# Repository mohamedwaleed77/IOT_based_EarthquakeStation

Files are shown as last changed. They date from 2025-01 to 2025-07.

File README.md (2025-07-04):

# 🌍 IoT-Based Earthquake Detection Station

An intelligent real-time seismic monitoring system designed to detect and classify earthquake activity. The project is composed of two main components:

- 📡 **Station Side** – Collects seismic acceleration data and sends it wirelessly via UDP.
- 🖥️ **Server Side** – Receives, processes, and classifies data using machine learning, and visualizes the results via a web dashboard.

---

## 🧱 System Architecture

A high-level overview of how data flows between the station and the server.

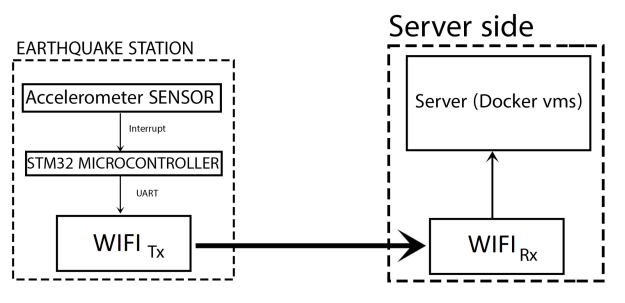
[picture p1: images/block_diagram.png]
System Block Diagram


---

## 🖥️ Server Side Overview

The server processes incoming seismic data and makes real-time predictions using a trained Random Forest model. It then updates a live web dashboard to notify users of potential earthquake activity.

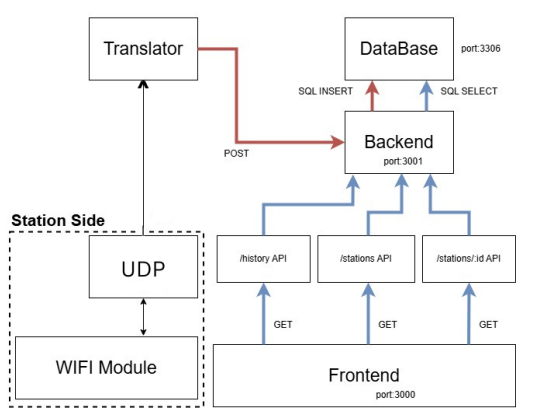
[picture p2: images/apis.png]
API Flow Diagram


---

## 🔩 3D-Printed Enclosure Design

The station hardware is housed in a custom-designed 3D-printed case to protect and organize components.

| Design Phase | Images |
|---|---|
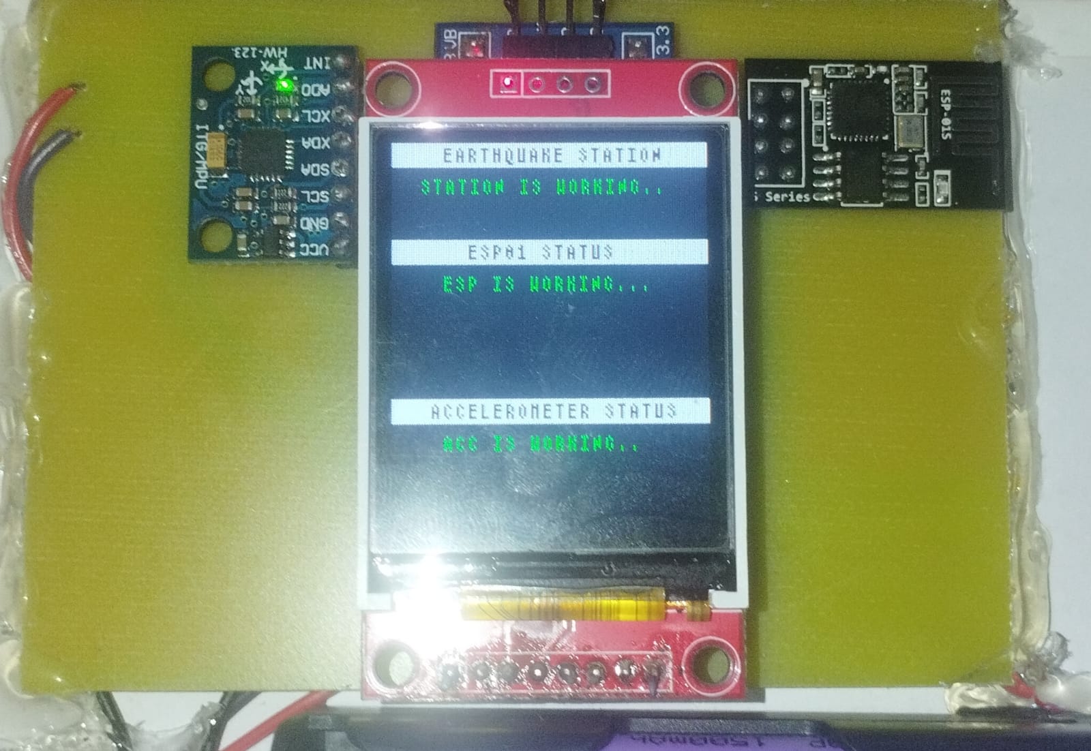
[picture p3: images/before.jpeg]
Before Assembly
| 📦 Before Assembly |  |
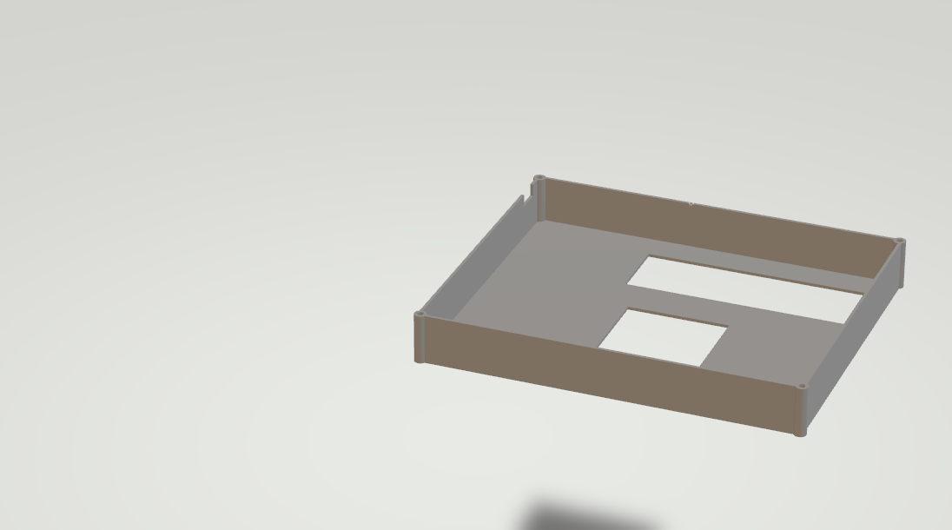
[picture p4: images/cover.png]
Cover
| 🧱 Case Cover |  |
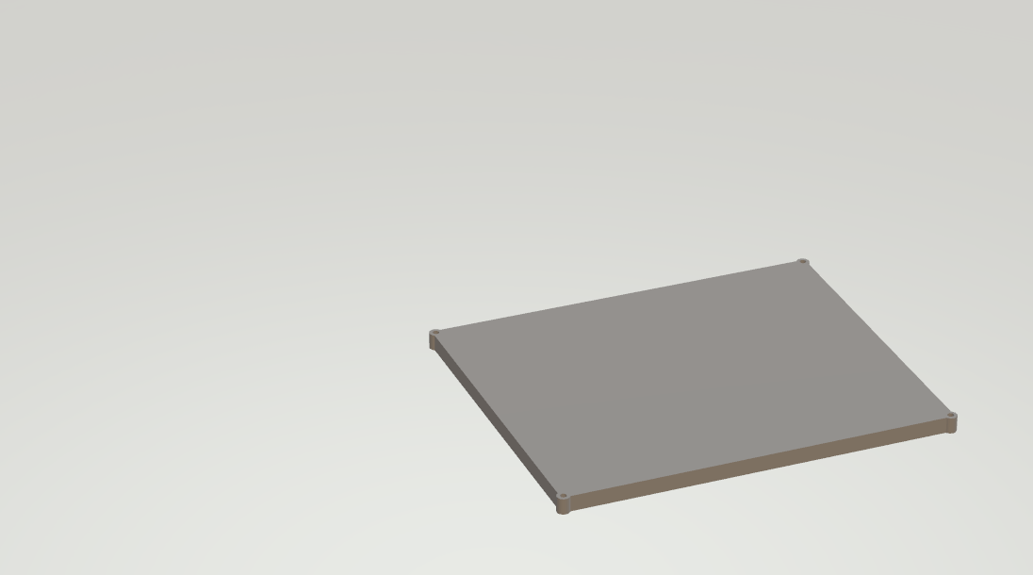
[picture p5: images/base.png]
Base
| ⚙️ Case Base |  |
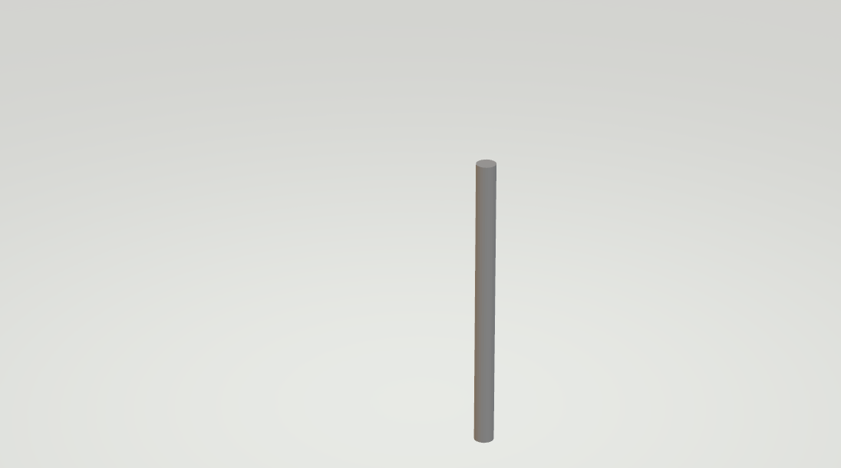
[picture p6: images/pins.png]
Pins
| 🔌 Pin Alignment |  |
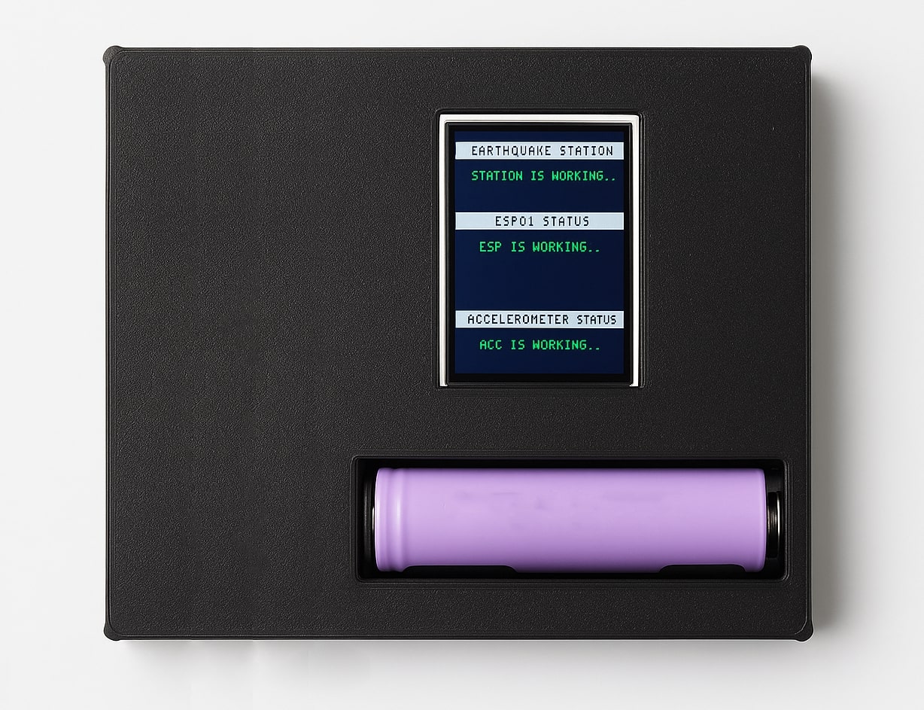
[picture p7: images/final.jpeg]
Final Assembly
| ✅ Final Assembly |  |
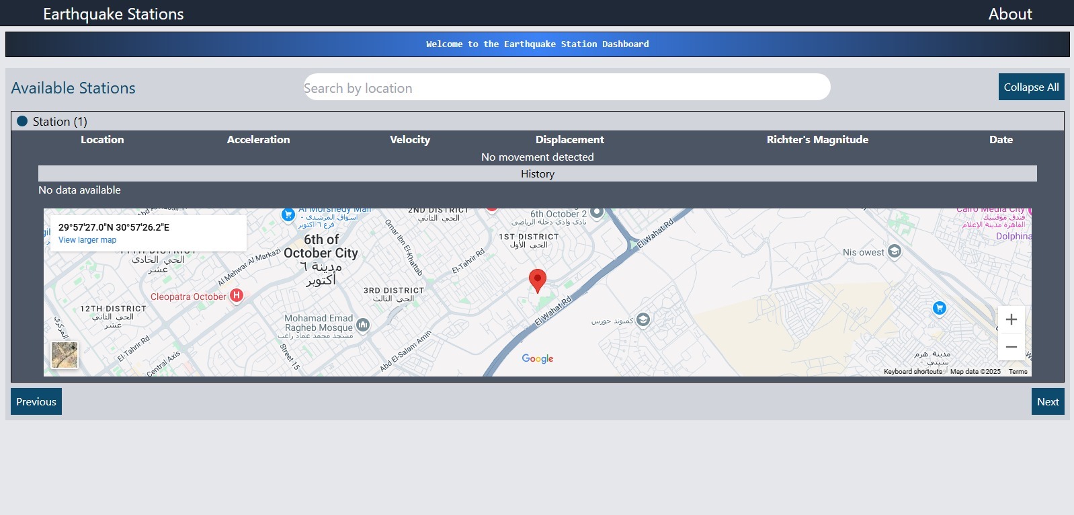
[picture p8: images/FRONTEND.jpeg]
Website
| 🌍 Website |  |

---

## 🛠️ PCB and Wiring Design

PCB and wiring layout for connecting the STM32 microcontroller to the accelerometer and Wi-Fi module.

| Design Phase | Images |
|---|---|
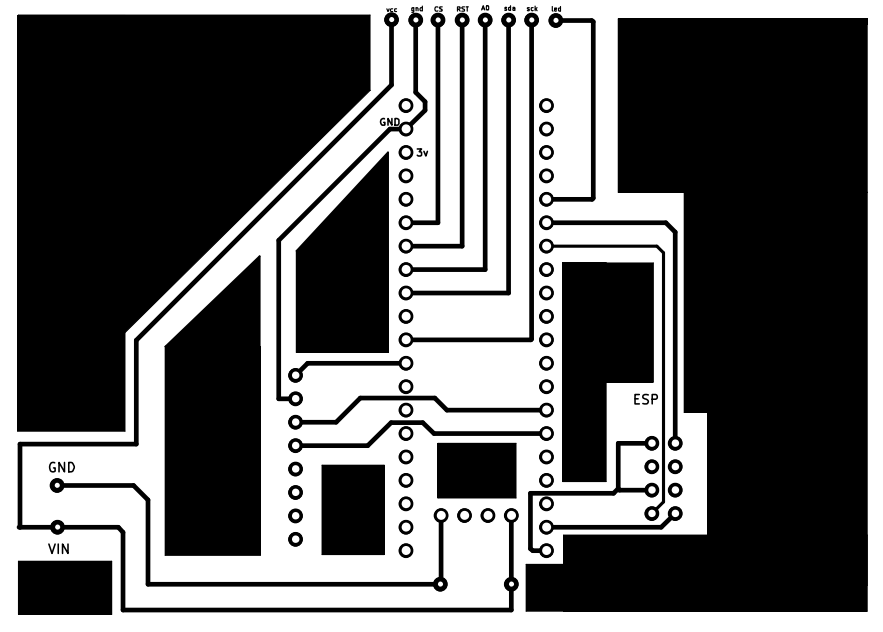
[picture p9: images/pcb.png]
PCB Design
| 🖨️ PCB Design |  |
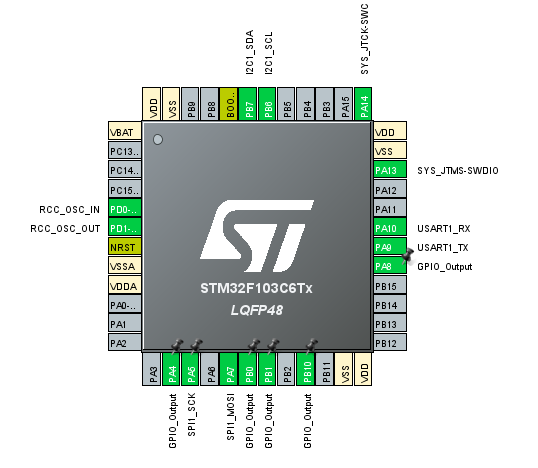
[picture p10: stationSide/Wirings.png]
Wirings
| 🔌 Wiring Diagram |  |

---

## 🚀 Key Features

- **Real-Time Seismic Detection** – Uses a calibrated accelerometer to monitor ground motion.
- **False Alarm Filtering with AI** – A Random Forest model classifies real earthquakes from non-seismic events.
- **Live Web Dashboard** – Displays live events and predictions.
- **Energy-Efficient Design** – Activates only during vibration for optimal power usage.
- **Modular and Scalable** – Easily deploy multiple stations for broader coverage.

---

## 🧠 How It Works

- The station samples acceleration data using an MPU-6050 sensor.
- If shaking is detected, the system transmits the first 200 acceleration readings via UDP.
- The server receives this data and classifies it using a pre-trained Random Forest model.
- If it’s an earthquake, the event is logged and displayed on a web interface.
- If its not an earthquake, the server chooses to ignore the data.

---

## 📁 Project Structure

```
.
├── Design Autocad/             # 3D-printed enclosure and mechanical design files
├── Machine learning Tests/     # Model evaluation, training notebooks, and experiments
├── backend/                    # Flask API for data ingestion and prediction
├── database_init/              # SQL database schema and initialization scripts
├── frontend/                   # Web dashboard for visualizing seismic events
├── images/                     # System diagrams, 3D prints, and screenshots
├── stationSide/                # STM32 code, sensor logic, and UDP transmission
├── Grad_Thesis_Book_Latex.pdf  # The graduation book 
└── README.md                   # Project overview
```

---

## 💡 Authors

- Abdulrahman Sallam  
- Mohamed Abdelfattah

---

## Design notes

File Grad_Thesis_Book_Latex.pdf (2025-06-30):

October University for Modern Science & Arts Faculty of Engineering

Department of Computer Systems Engineering

### IoT Wireless Earthquake Station

### A Graduation Project Submitted in Partial Fulfillment of the Requirements of

### B.Sc. Degree in Computer Systems Engineering

### Part II

### Prepared By Abdulrahman Alsayed Sallam 212421 Mohamed Waleed Abdelfattah 203659

### Supervised By Dr. Ehab Salaheldin Awad

2024/2025

Abstract

This project presents a cost-effective IoT-based Earthquake Station designed to detect seismic activity using an accelerometer and Wi-Fi for real-time data transmission. The system measures ground motion and operates only during seismic events, ensuring optimal energy efficiency, an essential feature for remote or off-grid locations. The system is only activated when needed. The project emphasizes reliable earthquake detection, efficient communication, and energy-saving techniques, adhering to a streamlined design approach. To address potential challenges, the agile development methodology is adopted, enabling flexibility and continuous refinement throughout the project lifecycle.

ii

Acknowledgement

We sincerely thank Dr. Prof. Ehab Salaheldin Awad for his great guidance and support in this project and for his supervision of our project. We are also grateful to Dr. Prof. Ahmed Ayoub and Dr. Prof. Ahmed Alenany for their invaluable advice and help.

iii

# Contents

1 Introduction | 1
2 Literature Review | 9
2.2.5 | Earthquake Detection Using Supervised Machine Learning and
3 Project Background | 29

iv

4 Proposed System Design | 53

v

4.4 Case Design | 67
4.5 Summary | 67
5 Implementation | 69
5.1 Hardware Implementation | 69
5.1.1 | Sensor Module (Seismic Data Acquisition) | 69
5.1.2 | Processing and Communication Unit | 70
5.1.3 | Power Management System | 71
5.2 Software Implementation | 71
5.2.1 | Firmware Development (STM32 - C Programming) | 71
5.2.2 | Server-Side Processing (Python) | 72
5.2.3 | User Interface | 73
5.3 System Integration | 73
5.3.1 | Sensor Layer | 74
5.3.2 | Communication Layer | 74
5.3.3 | Processing and Visualization Layer | 74
5.4 Summary | 75
6 Testing | 77
6.1 Testing Setup | 77
6.2 Testing Separate H/W or S/W Components and Units | 77
6.2.1 | Unit Testing | 77
6.2.2 | Integration Testing | 78
6.2.3 | System Testing | 78
6.2.4 | Testing Integrated System | 80
6.2.5 | A/B Testing | 80
6.2.6 | Test Cases | 81
6.3 Problems Encountered | 94
6.4 Results and Discussions | 95
6.5 Summary | 96
7 Cost Analysis | 97
7.1 One-Time Costs | 97
7.2 Recurring Cost | 98
7.3 Summary | 98
8 Time Plan | 99
9 Conclusions and Future Work | 101
9.1 Conclusions | 101
9.2 Future Work | 102

vi

References | 108

A System code
0.1 translator.py |
0.2 READINGS_ONLY.py |
0.3 docker-compose.yml |
0.4 Station Side Code |
0.4.1 | ESP01.h |
0.4.2 | ESP_01_SECRET_KEYS.h |
0.4.3 | MPU6050.h |
0.4.4 | fonts.h |
0.4.5 | main.h |
0.4.6 | st7735.h |
0.4.7 | ESP01.c |
0.4.8 | MPU6050.c |
0.4.9 | fonts.c |
0.4.10 main.c |
0.4.11 st7735.c |
0.5 Database Code |
0.5.1 | station.sql |
0.5.2 | database.js |
0.6 Frontend |
0.6.1 | index.html |
0.6.2 | index.css |
0.6.3 | index.js |
0.6.4 | App.test.js |
0.6.5 | reportWebVitals.js |
0.6.6 | setupTests.js |
0.6.7 | Introduction.js |
0.6.8 | about.js |
0.6.9 | history.js |
0.6.10 home.js |
0.6.11 navbar.js |
0.6.12 station_info.js |
0.7 Backend Code |
0.7.1 | checkStationExists.js |
0.7.2 | controller.js |
0.7.3 | routes.js |
0.7.4 | Dockerfile |
0.7.5 | index.js |
| vii

0.8 Machine Learning Models |

viii

List of Abbreviations

ANN | Aritificial Neural Network
API | Application Programming Interface
AUC | Area Under Curve
AWS | Amazon Web Services
BMKG | Meteorology, Climatology, and Geophysical Agency
CRNN | Convolutional-Recurrent Neural Network
EEW | Earthquake Early Warning
ER | Entity Relationship
FFT | Fast Fourier Transform
GSM | Global System for Mobile communication
HTTP | Hypertext Transfer Protocol
IDE | Integrated Development Environment
IMU | Inertial Measurement Unit
InSAR | Interferometric Synthetic Aperture Radar
IoT | Internet of Things
Kbps | Kilo bits per second
LTA | Long-Term Average
Mbps | Mega bits per second
MEMS | Micro-Electro-Mechanical Systems
MPU | Motion Processing Unit
MTBF | Mean Time Between Failures
ROC | Receiver Operating Characteristic
STA | Short-Term Average
STM | Synchronous Transport Module
SVD | Singular Value Decomposition
TP-link Twisted Pair link
UART | Universal Asynchronous Receiver-Transmitter
UDP | User Datagram Protocol
UI | User Interface
WEA | Wireless Emergency Alert

ix

x

# List of Figures

1.1 Block Diagram for Japan’s EEW [9] | | 3
2.1 Model for 19th Century Seismographs [3] | | 9
2.2 MEMS Accelerometer Model Diagram [19] | 10
2.3 Mugla Journal IoT-Based Earthquake Warning System General Design
[10] | 12
2.4 Lovely Professional University Earthquake System Block Diagram [11] . 14 2.5 Perwej, Dr. Yusuf & Jitendra Earthquake System Block Diagram [12] . . 16
2.6 ANN Model of Khan et al. System [16] | 18
2.7 Khan et al. Earthquake Alert Final Device [16] | 19
2.8 Direction Display to Evacuation Site Using Google Maps [15] | 21
2.9 Direction Display to Evacuation Site Using Google Maps [15] | 21
2.10 Notification Showing Earthquake Warning [15] | 22
2.11 UI of their Mobile Application [15] | 23
2.12 Mobile-Based Earthquake Early Warning System Architecture [15] . . . 23
2.13 Bassetti et al. using ESP8266 for the webserver | 26
3.1 Graph Between ∆ km and A0 | 35
3.2 Kobe Earthquake Acceleration Graph | 38
3.3 Kobe Earthquake Frequency Graph (After Fourier Transform) | 39
3.4 Cloud Server Architecture | 41
3.5 ROC Curve of Gradient Boosting Model | 43
3.6 ROC Curve of Gradient Boosting Model | 45
3.7 ROC Curve of LightGBM Model | 47
3.8 ROC Curve of Random Forest Model | 49
4.1 General Block Diagram of our System | 59
4.2 More Detailed Block Diagram for Server Side | 59
4.3 Block Diagram of How our API Works | 60
4.4 Use Case Diagram of our System | 61
4.5 Sequence Diagram of our System | 62
4.6 Activity Diagram of our System | 63

xi

4.7 Entity Relationship Diagram of our System | 64
4.8 High-Fidelity Wireframe of our System | 65
4.9 Circuit Diagram of our System | 66
4.10 PCB Design Diagram of our Station | 66
4.11 Case Design for the Station | 67
6.1 Earthquake Simulator Circuit Design with Bass Shaker | 79
6.2 Vibration Switch and Transistor Power Saving Solution | 94

xii

# List of Tables

2.1 Earthquake Detection ANN Models Results | 18
2.2 Comparison of Earthquake Detection Projects | 27
3.1 Comparison of Physical and Cloud Servers | 41
3.2 Naive Bayes Model Results for False Alarm Detection | 42
3.3 Gradient Boosting Model Results for False Alarm Detection | 44
3.4 LightGBM Model Results for False Alarm Detection | 47
3.5 Random Forest Model Results for False Alarm Detection | 48
6.1 Test case for seismic event detection | 81
6.2 Test case for power efficiency | 82
6.3 Test case for real-time web interface updates | 83
6.4 Test case for false alarm detection with frequency threshold | 84
6.5 Test case for Richter magnitude calculation | 85
6.6 Test case for sensor to STM32 communication | 86
6.7 Test case for STM32 to ESP-01 communication | 87
6.8 Test case for multiple station synchronization | 88
6.9 Test case for AI model integration for false alarm filtering | 89
6.10 Test case for full path data flow from accelerometer to web interface. . . 90
6.11 Test case for bass shaker-based earthquake simulation | 91
6.12 Test case for real-world earthquake detection | 92
6.13 Test case for cross-platform system compatibility using Docker | 93

8.1 Gantt chart illustrating the main project milestones, duration, and task
holder | 99

xiii

## Chapter 1

# Introduction

### 1.1 How Earthquakes Work

Earthquakes occur due to the sudden release of energy along faults in the Earth’s crust, typically caused by tectonic plate movements [1]. This release generates seismic waves that travel through the Earth, carrying vital information about the earthquake’s origin, magnitude, and intensity. Seismic waves are classified into three main types [2]:

- P-waves: The fastest seismic waves that travel through both solid and liquid layers of the Earth. They cause minimal damage but serve as the first indicators of an earthquake.
- S-waves: Slower than P-waves and capable of moving only through solid materials. These waves cause significant ground shaking and structural damage.
- Surface Waves: The slowest yet most destructive waves, responsible for the majority of structural damage during an earthquake.

### 1.2 Methods of Earthquake Detection

Traditional earthquake detection relied on seismographs, stationary instruments that record ground motion. Developed in the 19th century [3], these instruments provided the first quantitative measurements of earthquake intensity and location. However, they required centralized processing and lacked real-time capabilities, limiting their effectiveness for early warning applications.
With advancements in digital technology, earthquake monitoring has evolved significantly. Modern detection systems utilize accelerometers, which measure ground acceleration and detect sudden seismic events in real time. Micro-Electro-Mechanical Systems (MEMS) accelerometers have made earthquake detection more compact, cost-effective, and easily deployable in diverse environments [4].
One of the most critical aspects of modern earthquake detection is P-wave early warning systems. P-waves, which travel faster than S-waves and surface waves, can be detected before the more destructive shaking begins. By analyzing P-wave characteristics, it is possible to estimate the earthquake’s magnitude and provide early warnings seconds to minutes before the main shaking occurs [2].

### 1.2.1 Project Relevance and Contributions

Building upon these principles, our project aims to develop a cost-effective, energy-efficient, and scalable IoT-based earthquake detection system. By leveraging real-time P-wave analysis, signal processing techniques (such as Fast Fourier Transform), and efficient data transmission, our system enhances early warning capabilities. Unlike traditional seismic networks that rely on centralized data processing, our system is designed for distributed deployment, enabling faster and more localized detection.
By integrating modern accelerometer technology, real-time data transmission, and advanced signal processing, this project contributes to the ongoing efforts in earthquake early warning systems, offering a reliable and practical solution for seismic monitoring.

### 1.3 Problem Definition

Earthquakes are among the most powerful and unpredictable natural disasters, with an average of 20,000 occurring globally each year [5]. Most of these are minor and barely noticeable, but around 15 major earthquakes annually are capable of causing widespread destruction in mere seconds [6]. A tragic example is the 2011 Tohoku earthquake in Japan, which triggered a massive tsunami, resulting in nearly 20,000 fatalities and billions of dollars in damage [7]. Earthquakes strike without warning, collapsing buildings, disrupting infrastructure, and leaving communities in chaos. With such immense risks to human life and economic stability, it is critical to develop systems that can mitigate their impact through early detection and warning mechanisms. Although earthquakes cannot be predicted with certainty, early warning systems have been implemented in high-risk regions. Japan’s Earthquake Early Warning (EEW) system [8], shown in Figure 1.1, detects initial seismic waves (P-waves) and provides warnings seconds to minutes before the arrival of more destructive S-waves [2]. These systems enable automated responses such as halting trains, stopping surgeries, and issuing evacuation alerts, significantly reducing injury and damage.
However, while these centralized EEW systems are highly effective, they rely on large-scale sensor networks and extensive computational infrastructure, making them costly and inaccessible for low-income or remote areas. Additionally, continuous data transmission and centralized processing introduce latency and power consumption issues, limiting their feasibility for battery-powered or IoT-based deployments.

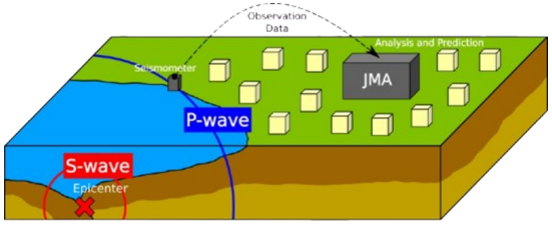
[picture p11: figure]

Figure 1.1: Block Diagram for Japan’s EEW [9]

Research Gap & Project Motivation: To address these challenges, this project proposes a cost-effective, energy-efficient, and scalable IoT-based earthquake detection system. By leveraging real-time P-wave analysis, optimized data transmission, and advanced signal processing techniques (such as Fast Fourier Transform), this system aims to improve early warning capabilities while minimizing power consumption and infrastructure requirements. Unlike traditional EEW systems, the proposed solution focuses on local detection and decentralized processing, allowing for rapid response even in resource-constrained environments.

### 1.4 State of the Art

1. IoT-Based Earthquake Detection Systems: Many modern earthquake detection systems, including our project, Mugla Journal IoT-based earthquake warning system[10], Lovely Professional University earthquake alert system [11], and Perwej et al.’s IoT-based seismic monitoring system [12], they all leverage IoT technologies to monitor seismic activity in real time. These systems utilize networks of accelerometers and other sensors to detect ground motion and transmit data for analysis. IoT-based earthquake detection systems offer several key advantages:
- Scalability: IoT networks enable the deployment of large-scale sensor arrays across various geographical regions, improving earthquake detection coverage.
- Cloud Integration: Many systems integrate with cloud computing for centralized data processing, storage, and real-time accessibility.
- Versatile Applications: These systems are used for various purposes, including early warning alerts, scientific research, and structural health monitoring.

2. Mobile-Based Earthquake Alert Systems: Systems such as ShakeAlert® in the United States [13], Ben et al.’s earthquake detection using GSM [14] and early warning system in mobile-based impacted areas [15] utilize smartphone networks and a combination of ground-based seismometers and mobile sensors to provide real-time earthquake warnings. These systems have proven to be highly effective but require significant infrastructure and government support for large-scale deployment. Key advantages of mobile-based alert systems include:
- Direct User Notifications: Alerts are delivered instantaneously to users via mobile applications, ensuring rapid dissemination of warnings.
- Leveraging Existing Infrastructure: These systems make use of cellular networks, making them highly scalable and cost-effective.
- Optimized for Urban Areas: Mobile-based alerts work best in densely populated regions with robust communication infrastructure, where quick warnings can help mitigate casualties.
3. Artificial Intelligence-Based Earthquake Detection Systems: Recent advancements in earthquake detection have incorporated Artificial Intelligence (AI) and Machine Learning (ML) techniques to enhance accuracy and reduce false alarms. Systems such as Khan et al.’s earthquake detection using supervised machine learning and novel feature extraction [16] utilize Artificial Neural Networks (ANNs) to classify seismic events based on extracted features from accelerometer data. These systems analyze time-series seismic data using feature extraction methods to differentiate between real earthquakes and background noise.

Key Advantages of AI-Based Systems:

- Improved Classification Accuracy: AI models can learn from vast amounts of seismic data, improving their ability to distinguish between actual earthquakes and false alarms.
- Adaptive Learning: Machine learning models can be retrained with new data, making them adaptable to different seismic conditions and regions.
- Feature Engineering for Enhanced Detection: The integration of advanced feature extraction techniques (e.g., FFT, SVD, MAX_ZC, and MIN_ZC) enhances the model’s ability to capture key earthquake characteristics.
- Reduced False Positives: Unlike threshold-based detection methods, AI systems can incorporate multiple features to refine decision-making, reducing false alarms caused by environmental vibrations.

Limitations of AI-Based Systems:

- Computational Cost: Training and deploying AI models require higher processing power, which may not be feasible for low-power embedded systems.
- Need for Large Datasets: ML models require extensive labeled seismic datasets for training, which may not always be readily available.
- Potential Overfitting: If not properly trained, AI models may overfit to specific types of seismic activity, reducing generalization to new events.
- No Current Reliable AI Based Warning: Currently due to how unpredictable earthquakes are, there’s no high accuracy AI’s that have been designed to create early warnings before the p-waves, however as AI continues to evolve in the future it can be used to predict earthquakes before they occur but to today standards unfortunately they can’t be used reliably, for example the best AI results for earthquake prediction before the P-wave was done by researchers at the university of Texas, where they were able to predict up to 70% of earthquakes before they happen in China, however their AI would only work in a specific area in china, they said "We’re not yet close to making predictions for anywhere in the world, but what we achieved tells us that what we thought was an impossible problem is solvable in principle" [17].

### 1.5 Aim and Objectives

We aim to To develop a cost-effective, energy-efficient, IoT-based earthquake detection system that leverages P-wave data to predict the final earthquake magnitude (Richter scale) in real time providing early warning before the more destructive S-waves arrive. We would achieve our aim by following these objectives:-

- Implement Real-Time Signal Processing: Design and apply filtering, Fast Fourier Transform (FFT), and Short-Term Average over Long-Term Average (STA/LTA) algorithms to extract relevant seismic features from acceleration data in real time.
- Develop Magnitude Estimation Algorithm: Implement a method for computing Richter magnitude using P-wave and S-wave arrival times and peak ground acceleration from sensor input.
- Integrate Hardware and Software: Program the STM32 microcontroller in C to manage sensor input, process data locally, and transmit relevant seismic data through a Wi-Fi-enabled IoT framework.
- Implement Event-Driven Activation Logic: Design a vibration-triggered mechanism that activates the system only upon detection of potential seismic motion, reducing unnecessary processing cycles.

- Support Multi-Station Operation: Architect the system to allow deployment of multiple independent detection nodes, with coordinated data aggregation for broader seismic coverage.
- Develop a Real-Time Monitoring Interface: Build a responsive web-based interface to visualize live seismic data, including detected events, sensor status, and historical trends.
- Evaluate System Accuracy and Reliability: Compare the system’s seismic event detection and magnitude estimation results with validated datasets, and iteratively adjust filtering thresholds and model parameters for improved performance.

### 1.6 Contributions and Uniqueness

- Cost-Effective Sensor Design: The system utilizes only an accelerometer rather than combining it with a gyroscope, reducing hardware costs while maintaining adequate accuracy through advanced signal processing techniques.
- Energy-Efficient Operation: A vibration-triggered mechanism ensures that the system activates only when seismic activity is detected. This targeted power usage conserves energy, making it ideal for deployment in remote or off-grid locations.
- Real-Time P-Wave Analysis for Early Warning: By processing P-wave data in real time, the system can predict the final earthquake magnitude before the arrival of the more destructive S-waves, thus providing crucial extra seconds for early warning.
- Robust IoT Integration: The system is built on an STM32 microcontroller, which offers low-level control and energy efficiency, coupled with Wi-Fi connectivity for real-time data transmission. This design supports centralized monitoring and scalable deployment across distributed sensor networks.
- Advanced Feature Extraction: Beyond standard metrics such as RMS acceleration, the system extracts detailed P-wave features including peak acceleration, duration, energy content, and frequency metrics (both peak and dominant frequencies) to enhance the accuracy of magnitude prediction.
- Adaptability and Scalability: The modular design allows for the easy integration of additional sensors or advanced algorithms (e.g., machine learning) in future iterations. This ensures that the system can be scaled and adapted to a variety of environmental conditions and evolving requirements.

### 1.7 Thesis Structure

This thesis is structured as follows:

- Chapter 1 - Introduction: Provides an overview of the project, including its objectives, significance, and a comparison with existing earthquake detection systems.
- Chapter 2 - Literature Review: Examines the principles of earthquake detection, signal processing techniques, and the evolution of seismic monitoring technologies.
- Chapter 3 - Project Background: Establishes the context and motivation behind the development of the earthquake detection system, highlighting real-world challenges, limitations of existing approaches, and the unique advantages offered by the proposed solution.
- Chapter 4 - System Design: Defines the system architecture, hardware components, software framework, and design specifications of the proposed earthquake detection system.
- Chapter 5 - System Implementation: Describes the hardware and software implementation, including microcontroller firmware development and the web-based monitoring platform.
- Chapter 6 - Testing and Evaluation: Discusses the testing methodologies, test cases, and evaluation results to validate the accuracy, reliability, and efficiency of the system.
- Chapter 7 - Cost Analysis: Provides a financial assessment of the system, covering hardware costs, operational expenses, and scalability considerations.
- Chapter 8- Time Plan: Showcases the main goal points of the project and how long the task will take with the usage of gantt chart.
- Chapter 9 - Conclusions and Future Work: Summarizes the findings, evaluates the project’s impact, and outlines potential future improvements to enhance system performance.

## Chapter 2

# Literature Review

### 2.1 History

The field of earthquake detection has undergone a remarkable evolution over the past two centuries. In its earliest days, detection relied on traditional seismographs—stationary instruments designed to record ground motion during seismic events. Developed in the 19th century, these early seismographs revolutionized our understanding of earthquake dynamics by providing the first quantitative measurements of seismic intensity and location. However, these instruments were limited by their immobility and reliance on centralized systems, which significantly hampered real-time detection and timely warning dissemination [18].

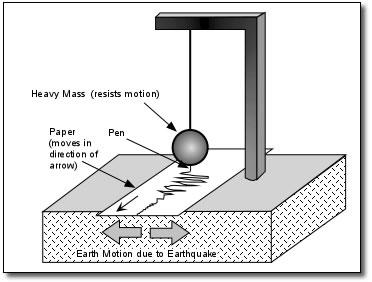
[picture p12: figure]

Figure 2.1: Model for 19th Century Seismographs [3]

The advent of digital technology in the late 20th century marked a major turning point. Computerized monitoring systems emerged, enabling faster and more accurate data processing. This digital revolution in seismology paved the way for the development of advanced methods capable of near real-time analysis of seismic events. Among the most significant breakthroughs was the invention of Micro-Electro-Mechanical Systems (MEMS) accelerometers. These sensors, with their compact size, low cost, and high sensitivity, have enabled the creation of scalable, IoT-based earthquake detection systems that are not only cost-effective but also capable of providing rapid alerts [4].

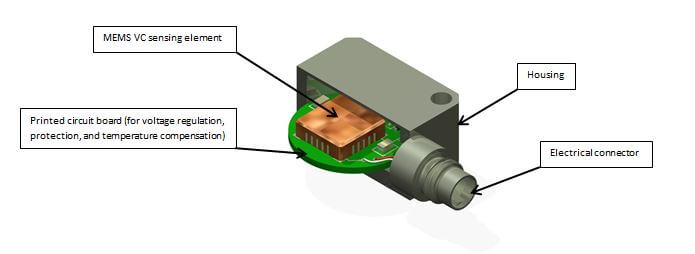
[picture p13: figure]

Figure 2.2: MEMS Accelerometer Model Diagram [19]

Today, modern earthquake detection systems integrate IoT frameworks, advanced signal processing, and real-time data analytics to monitor seismic activity continuously. This evolution from traditional, stationary seismographs to sophisticated digital systems underpins the development of innovative solutions like our proposed system, which combines cost efficiency with enhanced real-time capabilities and energy-saving operation.

### 2.2 Survey of Earthquake Detection Systems

In this section, we review several earthquake detection systems available in the literature. Each system is discussed in its own section to highlight its design, advantages, and limitations relative to our proposed solution.

### 2.2.1 Mugla Journal IoT-Based Earthquake Warning System

The system proposed in the Mugla Journal [10] presents an IoT-based earthquake early warning solution that monitors seismic activity in real time. It adopts a dual-sensor approach, integrating both an accelerometer and a gyroscope within an inertial measurement unit (IMU) to detect ground motion. This combination allows the system to capture both linear acceleration and angular velocity, thereby enhancing its sensitivity and ability to differentiate between various types of movement.
A key strength of the Mugla system is its effort to reduce false positives. This is achieved by deploying two identical sensor nodes in the same geographic area; an earthquake alert is only triggered if both nodes detect seismic activity concurrently. This redundancy minimizes false alarms from non-seismic events such as nearby construction or vehicular traffic. Once seismic activity is detected, the system transmits data via a Wi-Fi module to the ThingSpeak IoT analytics platform. ThingSpeak processes the data and disseminates earthquake alerts via Twitter, marking the beginning and end of the seismic event.
However, the system also presents notable drawbacks. First, the inclusion of a gyroscope increases hardware complexity and cost. Second, its reliance on ThingSpeak, a third-party cloud platform with a yearly subscription, introduces recurring costs and potential limitations in data ownership and customization. Most critically, the system does not estimate or classify the strength or magnitude of the earthquake, limiting its usefulness for damage prediction or severity assessment.
- Advantages of the Mugla System:

– Improved detection accuracy through dual-sensor integration (accelerometer + gyroscope)

– Redundancy via dual-node verification reduces false positives

– Real-time alerting via ThingSpeak and Twitter integration

– The usage of thingspeak eliminates the need for development on the server side making it simpler and faster release time.

- Disadvantages:

– Higher one-time cost due to gyroscope inclusion

– Higher recurring costs and limited customization due to reliance on ThingSpeak

– No quantification of earthquake magnitude

- Comparison with Our System:

Our system opts for a more cost-effective and maintainable approach by using only an accelerometer, which sufficiently captures the necessary ground motion data for detection while only a very slight reduction to sensitivity compared to a dual-sensor setup, it significantly lowers the overall cost and complexity of the hardware. Furthermore, unlike the Mugla system, we do not depend on external platforms like ThingSpeak. Instead, our system processes and stores data on a self-hosted server, eliminating subscription fees and offering greater control and data privacy.
Most importantly, our system includes an AI-powered module capable of determining whether a seismic activity is due to an earthquake or not based on acceleration patterns. This added layer of analysis addresses a critical shortcoming of the Mugla system and allows our solution to provide more actionable information for early warning and emergency response planning, our system is also capable of calculating the richter magnitude of an earthquake while mugla’s system can’t.
Figure 2.3 illustrates the general design of the Mugla Journal IoT-Based Earthquake Warning System.

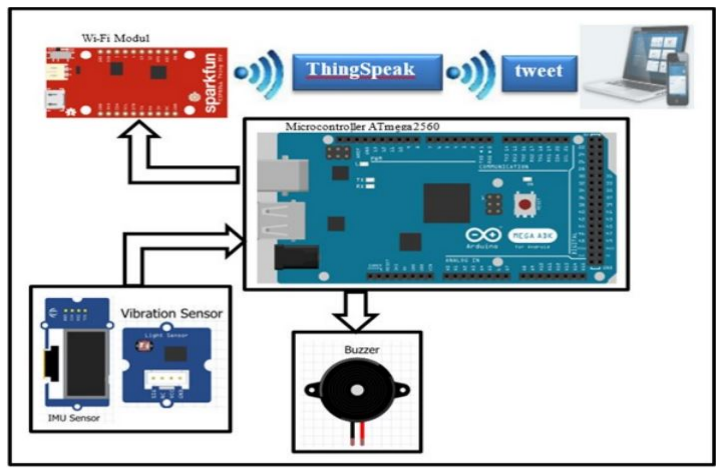
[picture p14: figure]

Figure 2.3: Mugla Journal IoT-Based Earthquake Warning System General Design [10]

### 2.2.2 Lovely Professional University Earthquake Alert System

The Earthquake Alert System developed by Lovely Professional University [11] is an IoT-based platform designed for real-time seismic monitoring and rapid dissemination of earthquake alerts. The system utilizes the ADXL335 accelerometer to capture ground motion, with data processed locally by an Arduino Uno equipped with an ATmega328P microcontroller. Seismic events are detected through a threshold based algorithm. When the sensed acceleration exceeds a predefined limit, the system transmits the data using a NodeMCU Wi-Fi module to the ThingSpeak cloud platform. On ThingSpeak, the data is visualized, logged, and used to trigger alert mechanisms.

One of the notable features of this system is its use of wireless sensor networks and real-time cloud communication to notify users through smartphones and web-based interfaces. This facilitates quick alerts and easy access to seismic data. However, the system’s detection logic is primarily based on thresholding high-amplitude accelerations, corresponding to the onset of strong shaking (S-waves). As a result, it lacks the capability to detect the initial, lower-magnitude P-waves that precede destructive earthquakes, reducing its effectiveness as a true *early* warning system. Additionally, reliance on the ThingSpeak cloud introduces recurring costs and restricts flexibility in customizing alert logic, data ownership, and integration with other systems. Furthermore, the system does not perform any form of magnitude estimation or advanced event classification, limiting its utility in post-event assessment and risk mitigation.

- Advantages of the Lovely Professional University System:

– Simple and cost-effective design using widely available components (e.g., ADXL335, Atmega328p, NODE MCU)

– Real-time alerts through ThingSpeak and smartphone/web interfaces

– Straightforward implementation of threshold-based detection

- Disadvantages:

– No detection of early P-waves, reducing warning time

– No estimation of earthquake magnitude or severity

– Dependence on ThingSpeak introduces recurring subscription costs and limits system customization

– Threshold-only detection may lead to missed detections or false positives

- Comparison with Our System:

While both systems are designed for real-time seismic monitoring, our system introduces several critical enhancements. First, instead of relying on only analog thresholding, our system incorporates an AI model trained to detect seismic activity patterns and incorporates an analog thresholding as well, which can reduce false positives and increase reliability. Additionally, we host our own backend server infrastructure, allowing full control over data storage, visualization, and alerting without incurring recurring cloud costs.
Unlike the Lovely Professional University system, our solution includes a module to estimate the intensity or magnitude of detected tremors, offering more context to users and responders. Although we also use an accelerometer-only setup for simplicity and cost efficiency, we overcome the limitations of thresholding by employing intelligent detection logic rather than fixed cutoffs.

Figure 2.4 presents the block diagram of the Lovely Professional University Earthquake Alert System, illustrating its sensor network, processing unit, and cloud communication architecture.

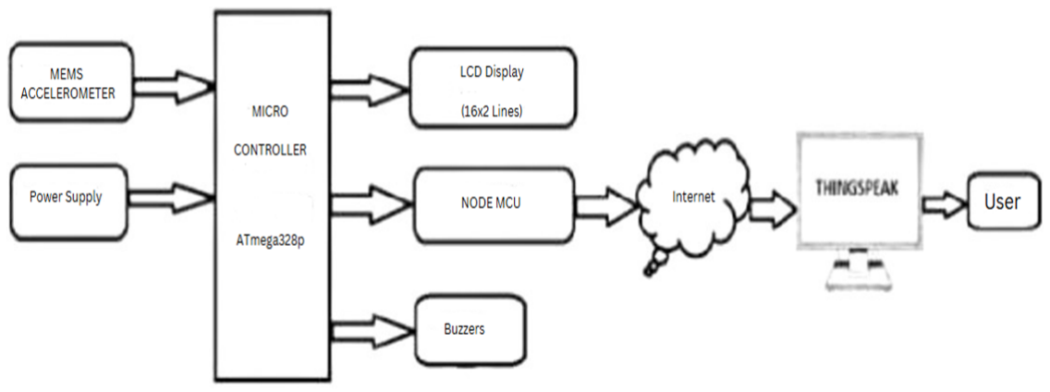
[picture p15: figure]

Figure 2.4: Lovely Professional University Earthquake System Block Diagram [11]

### 2.2.3 Perwej et al.’s IoT-Based Seismic Monitoring System

Perwej et al. [12] introduce an IoT-based seismic monitoring solution that utilizes a dual-sensor architecture comprising both accelerometers and gyroscopes. This approach enables the system to capture both linear and angular components of ground motion, significantly enhancing its ability to detect and characterize seismic events. By combining multiple data streams, the system can differentiate between actual earthquakes and non-seismic disturbances with higher accuracy.
One of the distinguishing features of this system is its capacity to detect P-waves relatively weaker seismic waves that travel faster and arrive before the more damaging S-waves. This early detection capability enables the issuance of alerts several seconds before significant ground shaking begins, which is crucial for public safety applications such as shutting down critical infrastructure or alerting populations at risk.
Sensor data is transmitted via an IoT communication protocol to a central processing hub, where advanced signal processing algorithms analyze the seismic activity. This architecture allows for scalable deployments, where multiple sensor nodes can be integrated into a wider network, improving both coverage and reliability. Furthermore, the system incorporates cross-verification from multiple sensors to reduce false positives, a technique particularly valuable in urban or industrial environments prone to background vibrations.

- Advantages of Perwej et al.’s System:

– Dual-sensor setup (accelerometer + gyroscope) provides richer data and more reliable event detection

– Capable of detecting P-waves for early warning before stronger shaking occurs

– Reduced false positives through signal cross-verification

– Designed to be cost-effective while offering real-time alerts

- Disadvantages:

– Increased hardware complexity and cost due to the use of multiple sensors

– Requires sophisticated signal processing infrastructure

– May not be suitable for ultra-low-power or highly resource-constrained deployments

- Comparison with Our System:

While Perwej et al.’s system excels in sensitivity and early warning by leveraging both accelerometers and gyroscopes, our system intentionally simplifies the sensor design by relying solely on an accelerometer. This choice was made to minimize hardware costs and power consumption, making our solution more suitable for wide-scale, costsensitive deployments.
To compensate for the absence of gyroscopes, our system employs machine learning-based classification to differentiate between real seismic activity and noise, aiming to maintain high detection accuracy while keeping the hardware lean. Additionally, unlike Perwej et al.’s reliance on a centralized processing node, our system performs local preprocessing before transmitting to a self-hosted web server, offering full control over the architecture and reducing dependency on third-party platforms.
While Perwej et al.’s architecture may be better suited for early warning scenarios in critical infrastructure, our system emphasizes accessibility, affordability, and control, making it ideal for grassroots-level deployments, schools, small businesses, and public buildings.
Figure 2.5 illustrates the detailed block diagram of Perwej et al.’s seismic monitoring system, highlighting its multi-sensor integration and real-time communication flow.

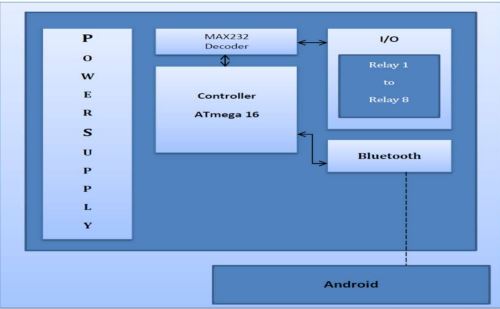
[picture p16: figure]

Figure 2.5: Perwej, Dr. Yusuf & Jitendra Earthquake System Block Diagram [12]

### 2.2.4 Ben et al.’s Earthquake Detection Using GSM

Ben et al. [14] propose a compact earthquake detection system that combines GSM communication with motion sensing via accelerometers and gyroscopes. This system is built around an Arduino microcontroller, which processes input from both types of sensors to detect seismic activity by capturing both linear and angular motion. Upon detection, the data is transmitted in real-time to a central monitoring unit using GSM technology, ensuring seismic events are promptly recorded and made accessible for further analysis.
A notable feature of this system is its hybrid communication strategy. While GSM is used for long-range data transmission, some configurations also support Wi-Fi for local connectivity, allowing flexible deployment in different environments depending on infrastructure availability.
However, the system primarily serves as a post-event monitoring tool, lacking the ability to issue pre-shaking alerts or detect early P-waves. This design choice simplifies implementation and reduces cost but limits its utility in applications requiring proactive safety measures, such as public warnings or automatic infrastructure responses.
- Advantages of Ben et al.’s System:

– Utilizes both accelerometers and gyroscopes for enhanced motion detection

– GSM module allows data transmission even in areas with limited internet infrastructure

– Flexible configuration supporting GSM and Wi-Fi

– Cost-effective and suitable for remote or underdeveloped areas

- Disadvantages:

– Lacks early warning capabilities (no P-wave detection or prediction)

– Primarily designed for data logging rather than immediate alerting

– GSM transmission may incur additional operational costs (SIM fees, data plans)

- Comparison with Our System:

While Ben et al.’s system focuses on post-event data transmission and is well-suited for archival and academic purposes, our system is optimized for real-time detection and proactive response. Unlike their GSM-based alerts, our system relies on Wi-Fi to send data to a private web server, giving us complete control over the processing, alerting, and data visualization pipeline.
Additionally, by relying solely on an accelerometer and machine learning-based event classification, our system reduces hardware complexity and cost, making it more scalable for widespread deployment. While we also forego P-wave-based early warnings due to sensor limitations, our real-time alerts and low-latency architecture allow us to respond almost immediately to the onset of shaking.
In summary, Ben et al.’s system is advantageous in remote or resource-limited environments with cellular coverage but lacks the predictive and customizable alert features of our solution.

### 2.2.5 Earthquake Detection Using Supervised Machine Learning and Novel Fea-

ture Extraction

Khan et al. [16] present an innovative approach to earthquake detection that leverages supervised machine learning techniques combined with a novel feature extraction method. Unlike traditional earthquake early warning systems that aim to forecast seismic events before they occur, this system focuses on real-time classification determining whether the current ground shaking is due to an earthquake or is merely noise or non-earthquake activity.
The proposed method extracts a comprehensive set of features from time-series sensor data, including both amplitude-based and frequency-domain characteristics. This system uses three features which are inter-quartile range (IQR), zero crossing rate (ZC), and cumulative absolute velocity (CAV). IQR is the range of acceleration values between the 25th and 75th percentiles, ZC counts how many times the acceleration signal changes sign, representing a frequency measure, and CAV summarizes the total amplitude of the acceleration vector sum across all three components. They then use these three features in an ANN model with three neurons in the input layer, five neurons in the hidden layer and one neuron in the output layer as seen in figure 2.6, this model is trained to distinguish between genuine earthquake signals and various forms of background noise, achieving promising results on both the training dataset and unseen data.

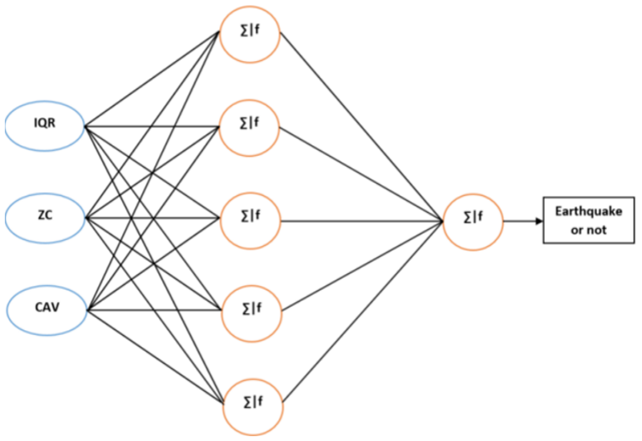
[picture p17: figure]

Figure 2.6: ANN Model of Khan et al. System [16]

A notable aspect of this study is its dual-environment approach: while the static model addresses challenges associated with sensor noise and fixed installations, the dynamic model is adapted to account for the complex vibratory patterns resulting from human activities. However, it is important to note that the system does not predict earthquakes before they occur—it merely classifies the current shaking as either an earthquake event or non-earthquake noise and then sends an alert to nearby devices using either Wi-Fi or Bluetooth.
They have tried six models with different features to see which would perform best, you can see the results in table 2.1.

Table 2.1: Earthquake Detection ANN Models Results

Model | TP | TN | FP | FN | Accuracy (%) | Precision (%) | Recall (%) | F1 Score (%) | Features Used
Model 1 | 698 | 23,987 | 129 | 312 | 98.24 | 84.40 | 69.11 | 75.99 | IQR, ZC, and CAV
Model 2 | 543 | 24,112 | 4 | 467 | 98.13 | 99.27 | 53.76 | 69.75 | IQR, FFT, CAV
Model 3 | 815 | 23,536 | 580 | 195 | 96.92 | 58.42 | 80.69 | 67.76 | IQR, ZC, FFT, CAV
Model 4 | 685 | 23,932 | 184 | 325 | 97.97 | 78.83 | 67.82 | 72.91 | IQR, SVD_ZC, CAV
Model 5 | 781 | 23,814 | 302 | 229 | 97.89 | 72.11 | 77.33 | 74.63 | IQR, ZC, CAV, SVD_Scale
Model 6 | 807 | 24,059 | 57 | 203 | 98.96 | 93.40 | 79.90 | 86.13 | IQR, CAV, MAX_ZC, MIN_ZC, MAX_NON_ZC

In the table, you may notice some more features mentioned earlier, those are the SVD which is a linear algebra technique that breaks down a matrix into three simpler matrices, facilitating easier analysis and manipulation [20]. The SVD is used for different features in some of the models, these features are SVD_Scale which is the first singular value (S[0]) representing the average amplitude characteristic and SVD_ZC which is the zero-crossing rate calculated for the primary vector, denoted as U[:,0].

The results indicate that Model 6 is the most effective, achieving the highest accuracy (98.96%) and F1 score (86.13%), demonstrating a strong balance between precision (93.40%) and recall (79.90%). The inclusion of MAX_ZC, MIN_ZC, and MAX_NON_ZC features likely enhances its ability to distinguish seismic events from background noise. Model 2, while highly precise (99.27%), suffers from poor recall (53.76%), meaning it fails to detect a significant portion of earthquake events. Model 3 has the highest recall (80.69%) but at the cost of low precision (58.42%), leading to frequent false positives. Models 4 and 5 show a more balanced approach with moderate precision and recall but do not outperform Model 6. Model 1 is a strong contender with high accuracy (98.24%) but slightly lower recall (69.11%), meaning it still misses some earthquake events. Overall, Model 6 provides the most reliable performance, making it the best candidate for deployment, while further improvements could focus on refining feature selection to optimize both precision and recall.

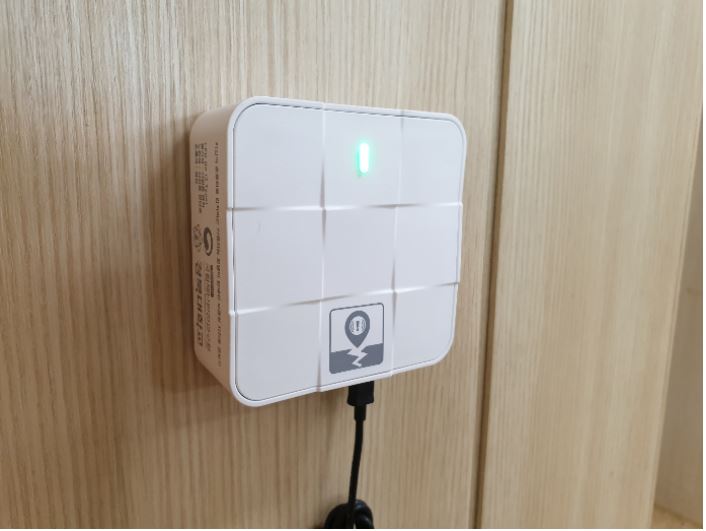
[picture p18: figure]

Figure 2.7: Khan et al. Earthquake Alert Final Device [16]

- Advantages

– Real-time classification using a lightweight ANN model makes it suitable for embedded systems.

– Utilizes simple yet effective features (IQR, ZC, CAV) that are interpretable and computationally efficient.

– Wireless communication via Wi-Fi or Bluetooth enables quick alerting without reliance on internet connectivity.

– The dual static/dynamic model design accommodates both fixed installations and human-induced vibration environments.

- Disadvantages

– The system does not predict earthquakes it only classifies current shaking.

– Effectiveness depends heavily on training data quality and may not generalize well to unseen noise types.

– Requires labeled datasets and feature engineering, unlike simpler threshold-based methods.

– While their accuracy is high, thats due to the high amount of noise data compared to the earthquake data, so if the model decides to just outputs a negative prediction then it would output a high accuracy anyways making the model biased.

- Comparison with Our System

Khan et al.’s system and our proposed system share the overarching goal of distinguishing between genuine earthquake events and other types of ground motion. However, the two approaches diverge significantly in terms of architecture, implementation, and objectives. Khan et al.’s work utilizes a compact Artificial Neural Network (ANN) model that operates locally using hand-crafted features such as inter-quartile range (IQR), zero crossing rate (ZC), and cumulative absolute velocity (CAV). Their model performs real-time classification directly on the device and then sends alerts via Bluetooth or Wi-Fi to nearby users. This makes their system suitable for small-scale, localized deployments that require fast, on-site decision-making.
In contrast, our system is designed for centralized, server-based analysis and is aimed at reducing false alarms rather than merely detecting shaking. We use a Random Forest model, which is more robust and interpretable than the lightweight ANN used by Khan et al., and better suited to distinguishing subtle differences between actual seismic activity and spurious signals. Our system streams acceleration data from the device to a web server where processing and classification take place, allowing for more complex analysis, scalability, and easier updates. Additionally, our system is powered by a constant electricity source with a battery backup, enabling it to run continuously in fixed installations. While Khan et al.’s system excels in local, embedded intelligence, our approach emphasizes reliability, scalability, and remote accessibility, making it better suited for long-term deployment and integration with centralized monitoring infrastructures.

### 2.2.6 Early Warning System in Mobile-Based Impacted Areas

The Early Warning System in Mobile-Based Impacted Areas [15] is a mobile-based earthquake alert system developed to enhance the effectiveness of earthquake notifications and evacuation guidance. This project was designed to address the shortcomings of conventional warning systems, which rely on TV, radio, and websites, often resulting in delayed dissemination of critical earthquake alerts. The system works as shown in Figure 2.8.

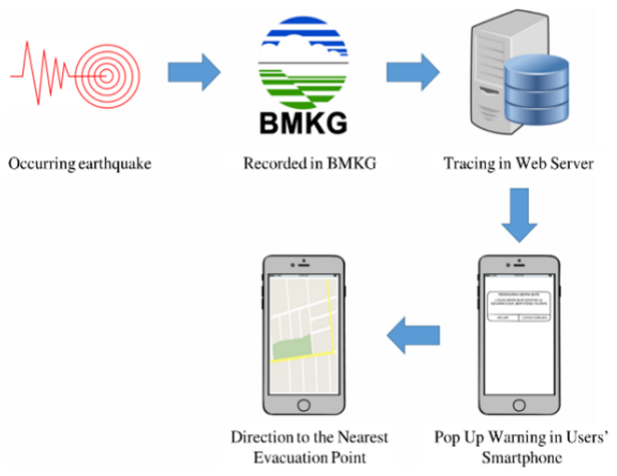
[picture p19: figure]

Figure 2.8: Direction Display to Evacuation Site Using Google Maps [15]

System Design and Functionality: The system leverages mobile technology and real-time data processing to deliver immediate earthquake warnings and evacuation directions. It integrates with:

- Google Maps API: Used to determine the user’s location and provide navigation assistance to the nearest evacuation site as seen in Figure 2.9.

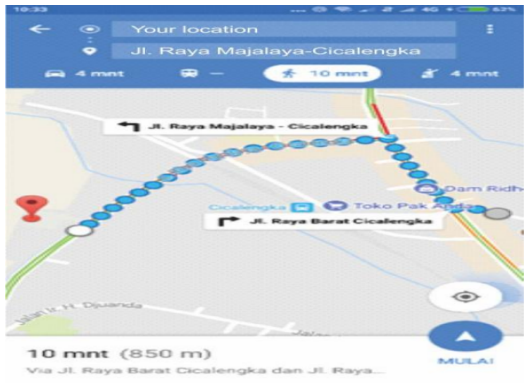
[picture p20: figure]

Figure 2.9: Direction Display to Evacuation Site Using Google Maps [15]

- Firebase Cloud Messaging (FCM): Enables instant notifications to users, accompanied by an alarm sound, ensuring that warnings are received promptly, as seen in Figure 2.10.

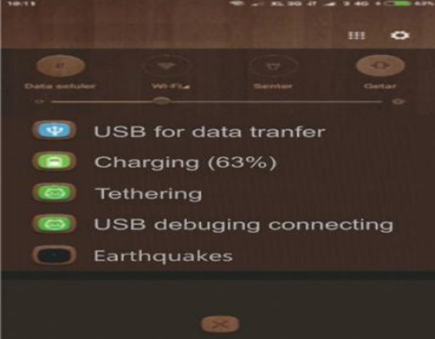
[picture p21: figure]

Figure 2.10: Notification Showing Earthquake Warning [15]

- BMKG (Indonesian Meteorological Agency) Data: The system fetches real-time earthquake data from BMKG’s monitoring network as seen earlier in Figure 2.8.

Key Features of the System Include:

- Instant Earthquake Alerts: Users receive mobile notifications with earthquake details as soon as seismic activity is detected, as seen in Figure 2.10.
- Evacuation Guidance: The system identifies nearby evacuation centers and provides real-time navigation using Google Maps, as seen in Figure 2.9.
- Historical Data Storage: Past earthquake records are stored in the application’s database for later review.
- User-Friendly Interface: Designed for accessibility, ensuring that even non-technical users can quickly understand and respond to alerts, as seen in Figure 2.11.

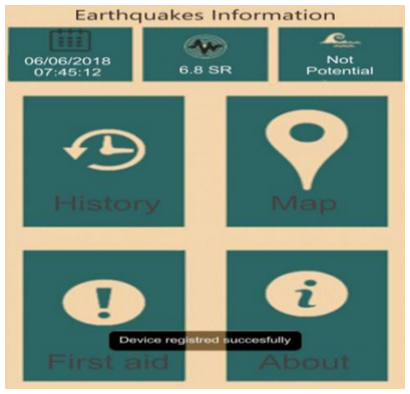
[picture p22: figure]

Figure 2.11: UI of their Mobile Application [15]

Advantages Over Conventional Systems: Compared to traditional earthquake warning methods, this mobile-based system ensures faster and more reliable notifications, particularly benefiting individuals who may not have immediate access to radio or television broadcasts. By utilizing smartphones, which are widely accessible, it significantly enhances community preparedness and response time during seismic events. Figure 2.12 illustrates the architecture of the mobile-based early warning system.

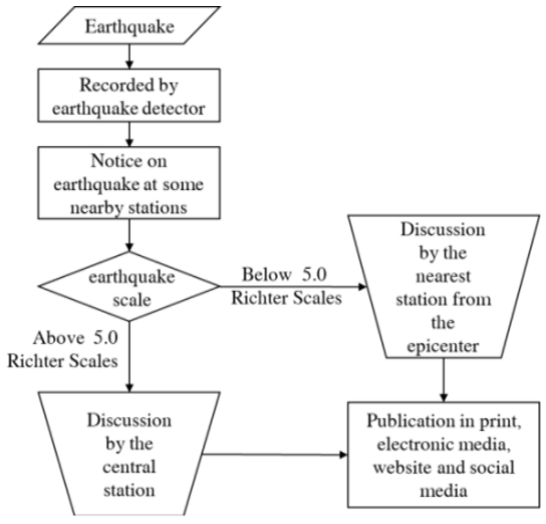
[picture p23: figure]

Figure 2.12: Mobile-Based Earthquake Early Warning System Architecture [15]

- Comparison with Our System
While the mobile-based early warning system by Moch et al. excels in disseminating alerts and guiding evacuation through smartphone notifications, it presents several limitations. It relies heavily on mobile networks and external data sources such as BMKG. This dependence introduces potential delays in detection and notification, especially in areas with poor connectivity or during disasters when networks may be congested or offline. Additionally, the system lacks local sensing capabilities, meaning it cannot directly detect seismic activity at the user’s location, which may reduce responsiveness to hyper-local events.

In contrast, our system includes a physical accelerometer that captures seismic activity in real-time at the point of measurement, independent of internet latency or third-party data providers. This sensor data is analyzed locally using a Random Forest classifier to filter out false alarms and accurately identify earthquakes.

While both of our systems make use of the Google Maps API, their usage is fundamentally different:

– Moch et al. use Google Maps to provide users with real-time evacuation guidance.

– Our system uses Google Maps within the web dashboard to visualize the geographic location of each sensor station, allowing users to correlate seismic activity with physical locations.

Moreover, our solution is designed to be web-based and infrastructure-resilient, capable of operating in fixed installations such as schools, factories, or public buildings. Unlike mobile-first systems, which prioritize portability and individual alerts, our focus is on precision, autonomous operation, and centralized monitoring for safety-critical environments.

While the mobile system offers mobility and user-facing features like historical browsing and navigation, our system delivers enhanced detection accuracy, lower latency, and deployment resilience—making it ideal for early-warning infrastructure that does not depend on mobile availability or cloud services.

### 2.2.7 Bassetti and Panizzi’s IoT Crowdsensing Edge Network

Bassetti and Panizzi [21] propose a decentralized IoT-based earthquake detection system that leverages edge computing to overcome the limitations of centralized fusioncenter-based architectures. Their system forms a partial mesh network where each detector node processes incoming data from probes and directly issues earthquake alerts via a gossiping protocol. Detection is done locally using a convolutional recurrent neural network (CrowdQuake), running on devices such as Raspberry Pi boards.

This architecture ensures resilience to node failure and improves user privacy by avoiding centralized cloud platforms. Data collected from NodeMCU-based probes (with ESP8266 and MPU6050) is streamed directly to a local detector, which also serves as the decision-making and alert-generating unit. The system is optimized for grassroots, decentralized deployment.

- Advantages of Bassetti and Panizzi’s System:

– Fully decentralized mesh network with no single point of failure – Low-latency local detection via edge-based ML (CRNN)
– Enhanced privacy by keeping data local
– Cost-effective hardware with open-source implementation
- Disadvantages:

– No estimation of earthquake magnitude
– No support for P-wave detection
– No central dashboard for remote monitoring or historical analysis – Very low sampling rate (10 Hz) which affects the accuracy
- Comparison with Our System:

While Bassetti and Panizzi’s system emphasizes full decentralization, we chose a more modular, maintainable architecture using a self-hosted centralized web server for processing, classification, storage, and alerting. Our microcontroller acts only as a data acquisition unit (accelerometer), sending readings to a centralized processor. This clean separation of roles makes updates, maintenance, and security far more manageable.
In fact, one of the reasons we avoided the Bassetti-style model is that it relies on letting each edge device act as both sensor and server. As shown in Figure 2.13, this “fully local” architecture introduces several key challenges:
- Scalability Issues: Edge nodes like ESP8266 and Raspberry Pi can only handle a limited number of connections, making public or institutional deployment difficult.
- Update Difficulty: Updating server logic requires physical access or complex automation to update firmware or containerized environments on each node.
- No Data Redundancy or Central Oversight: There’s no unified dashboard, backup, or long-term analytics capability.

Thus, while Bassetti’s system offers high fault tolerance and decentralization, it lacks centralized control, scalable infrastructure, and rich feature sets like magnitude estimation or false alarm classification, which are integral to our solution.

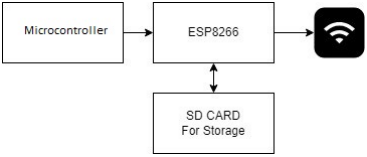
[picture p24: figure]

Figure 2.13: Bassetti et al. using ESP8266 for the webserver

### 2.3 Summary

The evolution of earthquake detection systems has progressed significantly, transitioning from traditional mechanical seismographs to modern IoT-based and mobileintegrated solutions. Early earthquake monitoring relied on stationary seismographs, which provided essential but delayed information about seismic events. The introduction of digital computing and MEMS accelerometers revolutionized the field, enabling real-time seismic data acquisition and efficient early warning capabilities. Through our survey of existing earthquake detection systems, several approaches were identified:

- IoT-Based Systems: Platforms like the Mugla Journal System [10] and Perwej et al.’s IoT Seismic Monitoring System [12] employ networked sensors for real-time data collection and cloud-based processing.
- Threshold-Based Detection: Solutions like the Lovely Professional University Earthquake Alert System [11] rely on Richter magnitude thresholds, making it difficult to detect early, low-intensity P-waves. This limits their ability to provide early warnings before strong shaking begins.
- GSM and Wireless-Based Detection: Systems such as Ben et al.’s GSM-Based Earthquake Detection [14] focus on data transmission via cellular networks, ensuring real-time monitoring but lacking pre-earthquake alerts.
- Machine Learning-Based Classification: The ANN model developed by Khan et al. [16] introduces feature extraction and artificial intelligence for earthquake classification. However, this system does not predict earthquakes but rather distinguishes between seismic events and background noise.
- Mobile-Based Warning Systems: Projects like the Early Warning System in Mobile-Based Impacted Areas [15] leverage smartphone notifications, GPS mapping, and cloud messaging to quickly alert users and guide them toward safety.

- Edge-Based Decentralized Detection: The system by Bassetti and Panizzi [21] uses a fully decentralized mesh network of detectors that locally process seismic data using a CRNN model. Their edge-computing approach enhances privacy, fault tolerance, and latency but does not estimate magnitude and lacks centralized coordination or redundancy.

Comparison to Our Proposed System: While existing solutions provide valuable insights, many suffer from high energy consumption, infrastructure dependency, or delayed warnings due to reliance on post-event magnitude detection or limited signal interpretation. In contrast, our system integrates a Random Forest classifier, magnitude estimation, and real-time filtering to provide an efficient, cost-effective, and power-saving early warning solution. By leveraging STM32 microcontrollers, Wi-Fi communication, and a robust detection algorithm, our system offers an innovative approach to accurate, rapid, and scalable earthquake warnings.
Future Directions: Advancements in earthquake detection will likely continue to integrate machine learning, edge computing, and decentralized IoT sensor networks, further improving the accuracy, scalability, and responsiveness of early warning systems. Our project aims to contribute to this evolution by offering an efficient, adaptable, and cost-effective alternative.

Table 2.2: Comparison of Earthquake Detection Projects

Features | Our Project | Mugla Journal IoT-Based Earthquake Warning System [10] | Lovely Professional University Earthquake Alert System [11] | Perwej et al. IoT-Based Seismic Activity Monitoring [12] | Ben et al. Earthquake Detection Using GSM [14] | ANN-based Earthquake Detection [16] | Bassetti and Panizzi IoT Edge Network [21]
Sensors Used | Accelerometer | Accelerometer & Gyroscope | Accelerometer | Accelerometer & Gyroscope | Accelerometer & Gyroscope | Accelerometer | Accelerometer (in probe)
Data Transmission Method | Wi-Fi STM32 [22] (for | Wi-Fi | Wi-Fi | Bluetooth | Wi-Fi | Wi-Fi/Bluetooth | Wi-Fi (probe) to local Raspberry Pi Microcontroller
| low-level control and optimization) | ATmega2560 | ATmega328p | Atmega16 | Arduino | 32-bit single-core ARMv6 processor | ESP8266 (probe) & Raspberry Pi (detector)
Early Earthquake Warning | Yes | Yes | No | Yes | No | Yes | Yes
AI Model Used | Random Forest | None | None | None | None | Artificial Neural Network (ANN) | Convolutional Recurrent Neural Network (CRNN)

## Chapter 3

# Project Background

### 3.1 Accelerometer results unit

### The accelerometer measures acceleration in units of g force (g) where

### 1 g is equal to 9.81m/s

2

### , the acceleration caused by Earth’s gravity. It

provides acceleration values along three axes: x, y, and z.

### The total acceleration or magnitude can be calculated using the follow-

### ing equation:

## let g = 9.81m/s

2

## Total Acceleration Magnitude (m/s

2
) =
p
(x · g)

2 + (y · g)

2 + (z · g)

2

Where x, y and z are the acceleration values along the respective axes.

Since the Richter magnitude scale measures ground displacement rather than acceleration, a logarithmic conversion is required to translate the accelerometer’s acceleration data into a more understandable measure of earthquake size. This conversion involves comparing the total acceleration magnitude to a reference amplitude, which aids in estimating

the energy released during the earthquake.

### 3.2 Acceleration to Displacement conversion

### 3.2.1 Conversion Overview

### Every 0.1 seconds, the microcontroller will retrieve the raw data from the accelerometer for the x, y, and z axes. This data will then be converted into magnitude. After 1 second, a total of 10 magnitudes will be obtained. During this 1-second interval, each of these magnitudes will

be integrated to convert them into displacement.
First step: Integrating accelerations to get velocity.

v(t) = Z
a(t)dt

Second step: Integrating velocities to get displacement.

### d(t) = Z

v(t)dt

Note: Here, t is fixed to 0.1s as the operation will occur every 0.1s.

### 3.2.2 Integration Calculations

### Here, we will use the trapezoidal rule [23] for its simplicity and better use of the computing power:

S =

∆t
2

### - (f(t1) + f(t2))

### Where

S: Area under the curve (integral).
∆t: Time step between samples.

f(t): Function (acceleration or velocity in this case).

### Using the trapezoidal rule, the acceleration is integrated over time to obtain the velocity. The trapezoidal rule approximates the area under the curve of a function

First Integration: Acceleration to Velocity

v(t) = vprev +

∆t
2
- (aprev + acurrent)

### where v(t): Current velocity

### vprev: Previous velocity ∆t: Time interval between samples (0.1s)

aprev and acurrent: Previous and current acceleration values.

Second Integration: Velocity to Displacement

d(t) = dprev +

∆t
2
- (vprev + vcurrent)

### where d(t): Current displacement dprev: Previous displacement ∆t: Time interval between samples (0.1s)

vprev and vcurrent: Previous and current velocity values.

### 3.2.3 Sampling

### To improve accuracy, we can reduce the time between callback interrupts to 100ms or less, and adjust the value of the dt variable accord-

ingly.
For example:
- dt = 0.05 and timer callback = 0.05s

### This will give us:

1

### 0.05 = 20 samples per second

- dt = 0.01 and timer callback = 0.01s

### This will give us:

1

### 0.01 = 100 samples per second

- dt = 0.001 and timer callback = 0.001s

### This will give us:

1

### 0.001 = 1000 samples per second

### That’s the maximum number of samples we can get in 1 second because our accelerometer (MPU-6050) output data rate has a maximum

frequency of 1000 Hz [24].

### However to keep the station in lower power consumption mode we will remain using dt = 0.1 and timer callback = 0.1s until it’s proven to have

a noticeable issues with accuracy.

### 3.2.4 Richter Conversion

### After accelration is converted to displacement, the next step is evaluating Richter’s magnitude using the following equation [25]:

ML = log10(A) − log10(A0)

### Where A0: the Reference amplitude depending on the distance of the station

from the earthquake’s epicenter.
A: Amplitude of the seismic wave (Dmax in this case).

To calculate A we would just take the amplitude of seismic waves,

### while A0 we would need to calculate the distance to the epicenter then convert it to A0 [25] so to calculate the distance to the epicenter we would use this equation [26]:

ED = 8.4(S − P)

### Where ED: Epicentral distance in kilometers

S: Arrival time of the first S-wave in seconds.
P: Arrival time of the first P-wave in seconds.

As you see in the equation, we need to find how to get the P-wave and S-wave arrival time, as mentioned before our station only works when it detects a vibration, so the arrival time for the P-wave would always be at 0 seconds. For the S-wave arrival time we will use STA/LTA ratio which is a measurement used in signal processing and seismology to detect sudden changes in a signal. The STA/LTA ratio highlights the moments when there is a sudden increase in signal energy, making it

easier to identify wave arrivals [27].

### To calculate the STA we would use this equation [28]:

### STA(t) = 1

N

t
∑

i=t−N+1

|x(i)|

### Where

N: Number of samples for the short-term window. x(i): Signal amplitude at time i.

### Then to calculate the LTA we would use this equation [28]:

### LTA(t) = 1

M

t
∑

i=t−M+1

|x(i)|

### Where

M: Number of samples for the long-term window.

### Then to calculate the STA/LTA ratio we simply divide the STA with LTA [28]: STA/LTA Ratio(t) = STA(t) LTA(t)

### The STA/LTA ratio is monitored in real time. When the ratio surpasses a predefined threshold, it is used to mark the estimated arrival of the S-wave. Otherwise, the system continues to monitor until this

condition is met.

### LTA is rarely ever 0, however if LTA is 0, then to avoid errors from oc-

curring we would simply make the STA/LTA ratio 0.

### After calculating the Epicentral distance, we then can convert it into −log10(A0) using the following graph:

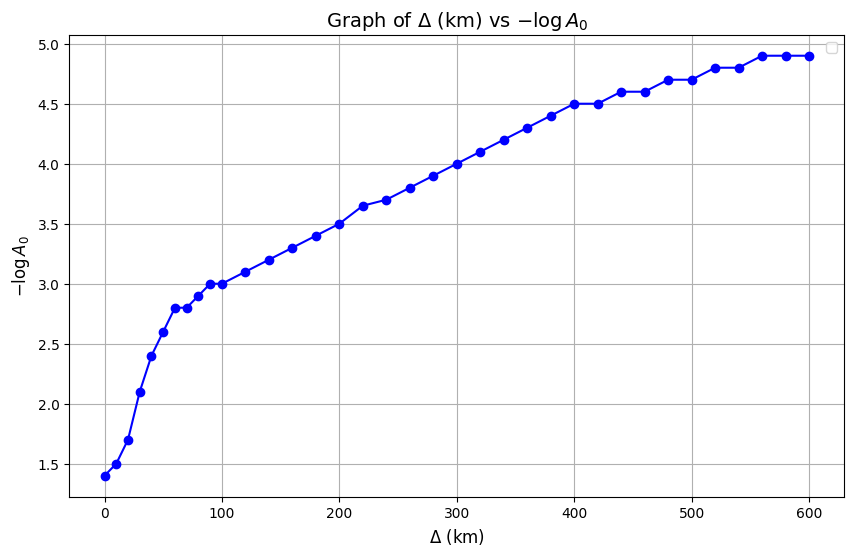
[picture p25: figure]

Figure 3.1: Graph Between ∆ km and A0

### Which follows this equation:-

### y = −1.6077510⁻¹⁰ x

4 +2.142910⁻⁷
x

3 −0.000100878 x

2 +0.023678 x +1.45704

### where

x: Is the epicentral distance. y: Is the -log(A0).

### 3.3 Earthquake Frequency

Seismic waves generated by earthquakes cover a broad range of frequencies, which are crucial in understanding how earthquakes affect structures and are detected by seismic instruments. The frequency content of an earthquake primarily depends on the magnitude, depth, and geological conditions of the region.

### 3.3.1 Classification of Earthquake Frequencies

Seismic waves can be classified based on their frequency ranges:

- High-Frequency Waves (1 - 20 Hz): These waves are associated with small to moderate earthquakes and typically have shorter wavelengths. They are more destructive to smaller structures such as houses and bridges [29].
- Low-Frequency Waves (0.001 - 0.1 Hz): Generated by large earthquakes, these waves have long wavelengths and can travel significant distances. They primarily affect tall buildings, bridges, and large infrastructure projects [30].

### 3.3.2 Frequency of P-Waves and S-Waves

P-waves (primary waves) and S-waves (secondary waves) have different frequency characteristics:

- P-Waves: These are the fastest seismic waves and typically have higher peak frequencies (1–20 Hz) [31]. Since they arrive first and are minimally destructive, they are useful for early warning systems.
- S-Waves: These waves travel slower than P-waves and generally have lower peak frequencies (0.01–5 Hz). They cause stronger ground shaking and are responsible for most of the damage in an earthquake.

### 3.3.3 Impact of Frequency on Earthquake Detection

The frequency of seismic waves plays a critical role in earthquake detection and monitoring. High-frequency waves attenuate faster, limiting their detection range, while low-frequency waves travel longer distances with less energy loss. This distinction is important in designing sensor networks:

- Low-frequency waves are more detectable by broadband seismometers, which are used for monitoring large-scale seismic events.
- High-frequency waves are crucial for detecting near-field earthquakes and providing rapid alerts.
- Filtering techniques, such as band-pass filters, are applied to distinguish seismic signals from environmental noise.

### 3.3.4 Relevance to This Project

In this project, our earthquake detection system utilizes frequency thresholds to distinguish between normal ground vibrations possibly caused by a car or a truck driving by for example, and potential seismic events by analyzing the dominant frequencies in acceleration data.
Understanding earthquake frequency characteristics is essential for optimizing detection algorithms and ensuring reliable real-time monitoring, so we need to find a way to turn our acceleration data into frequency.

### 3.4 Acceleration to Frequency

We need a way to be able to differentiate between if something is an earthquake or for example if its a car driving by, and to differentiate between those we decided to use frequency, and in order to get the frequency we would use fourier transform.

### 3.4.1 Fourier Transform

Fourier transform is a mathematical operation that converts a given function into another, revealing how much of various frequency components are present in the original function [32].

Fourier transform is done using the following equation:-
F(f(t)) = F(w) = Z ∞

−∞

f(t)e

−jwt dt

- f(t): Original function in the time domain. (in our case the acceleration or velocity function)
- F(w): Resulting function in the frequency domain.
- w: Angular frequency.

To determine the dominant frequency, we take the acceleration function, apply the Fourier transform, and extract the peak frequency component, which represents the most significant oscillatory behavior in the data. However, computing the Fourier transform directly can be computationally expensive, especially for real-time earthquake detection and it would take more time therefore we’ll use something called fast fourier transform.

### 3.4.2 Fast Fourier Transform (FFT)

To improve computational efficiency, the FFT algorithm is employed. FFT is an optimized implementation of the Discrete Fourier Transform (DFT) that reduces computational complexity from O(N²
) to O(N log N) [33], making real-time processing feasible.
FFT operates using a divide-and-conquer approach, recursively breaking down the input signal into smaller components. It exploits symmetries in the Fourier transform, particularly the periodicity and redundancy of complex exponentials, to significantly reduce computation time.
In the earthquake detection system, FFT is used to analyze acceleration signals from the MPU-6050 sensor. By transforming the time-domain acceleration data into the frequency domain, the system can:
- Extract dominant seismic frequencies.
- Differentiate between normal vibrations and earthquake events based on spectral characteristics.
- Enhance real-time processing efficiency, ensuring fast response times for early warning capabilities.

This approach allows the system to achieve accurate and reliable seismic event detection while maintaining computational efficiency, making it suitable for real-time earthquake monitoring applications.

### 3.4.3 Example of Acceleration to Frequency

To showcase an example we’ll use an actual earthquake data, we’ll use data from Kobe 1995-01-16 earthquake from the strong-motion virtual data center [34], Firstly we’ll use the acceleration graph

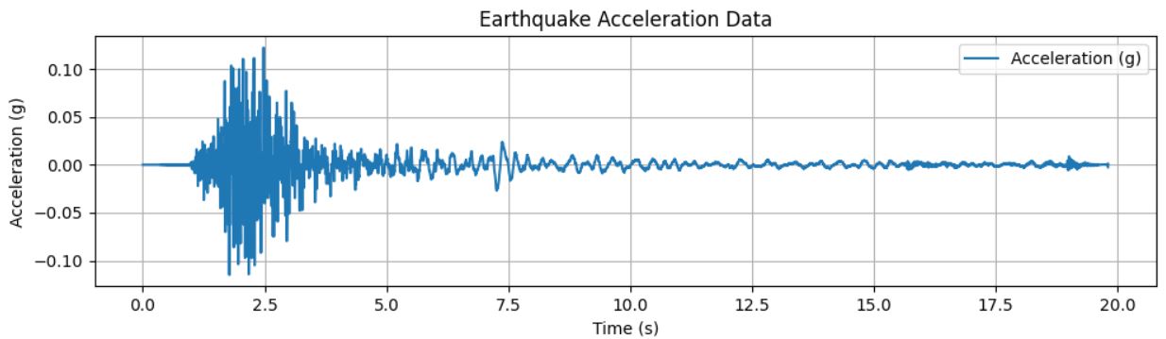
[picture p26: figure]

Figure 3.2: Kobe Earthquake Acceleration Graph

Next, we take the acceleration graph and apply FFT on it, turning the graph into frequency just as seen in figure 3.3.

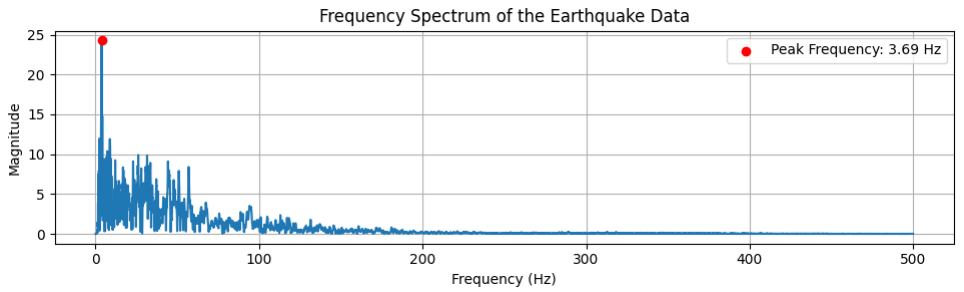
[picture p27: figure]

Figure 3.3: Kobe Earthquake Frequency Graph (After Fourier Transform)

We could use either acceleration or velocity or displacement graph to get the frequency however we chose to use the acceleration because to get the velocity or displacement calculations would need to take place but with acceleration we get it right away from the accelerometer readings so using the acceleration would be faster in determining whether its an earthquake or not. Now it’s needed to determine the earthquake frequency, as you notice in the graph seen in figure 3.3 we have highlighted the peak frequency, that’s because we will use that as the earthquake frequency so for this earthquake it would have a frequency of 3.69 Hz, as you may have noticed the frequency fits earthquakes since they can have frequency ranging from 1 - 20Hz [29] so to differentiate between an earthquake and other kinds of vibrations we would conclude that any earthquake with a frequency of between 1-20 Hz would be considered as a possible earthquake.

### 3.5 Server Side

A critical component of this project is the server side, which serves as the central system for receiving, processing, storing, and displaying data collected from the earthquake detection stations. The server not only acts as a reliable data aggregator but also ensures real-time visualization and remote accessibility. This backend infrastructure must be both modular and platform-agnostic to allow easy deployment and maintainability.

To meet these requirements, we used Docker as our primary deployment strategy. By containerizing each service (database, backend, frontend), we can guarantee consistent behavior regardless of the underlying host environment be it Windows, Linux, physical hardware, or a cloud instance. All that’s required is Docker, thereby eliminating dependency management concerns.

### 3.5.1 Physical Server

As shown earlier in Figure 4.2, our physical server architecture deliberately keeps one key component the Python data handler script outside the Docker environment. This script is crucial, as it acts as a mediator between the ESP-01 Wi-Fi module (which transmits raw sensor data) and the Dockerized services. Keeping it outside the container provides direct access to local ports and allows for low-latency, reliable communication with hardware interfaces.
The Python script then relays the cleaned and structured data to the backend service inside a container. The backend connects to a MySQL container that stores earthquake event data in a persistent volume. Docker volumes ensure data durability even when containers are restarted or updated.
Although combining the backend, frontend, and database into a single image could simplify deployment, we intentionally chose to implement a microservices architecture. This modular design allows each component to be independently updated, tested, scaled, or replaced enhancing the system’s long-term maintainability and flexibility.
To make the physical server accessible over the internet, especially for remote monitoring, we use router-level features such as the Virtual Server (port forwarding) available in TP-Link routers. This provides external access to our local server while maintaining sufficient control over network security.

### 3.5.2 Cloud Server

In the cloud-hosted version of the server, depicted in Figure 3.4, we redesign the communication pipeline to eliminate the need for a local Python handler. Instead, the ESP8266 microcontroller sends data directly to a public HTTP endpoint, typically hosted on a cloud-based virtual machine or serverless backend.
This transition is made possible because the ESP8266 supports both Wi-Fi connectivity and HTTP communication, enabling it to send real-time data to a remote database via RESTful API calls.
The ESP8266 was selected for the following reasons:
- Wi-Fi support: Easily connects to existing networks without extra modules.
- Built-in HTTP request capability: Can post data directly to a backend.
- Cost-effectiveness: Offers a great balance between features and price.
- Optimal performance: More efficient than the minimal ESP-01 and more appropriate (cost-wise) than the ESP-32 for this specific task.

This approach significantly reduces the server’s dependency on local hardware, improving scalability and enabling seamless deployment across multiple locations.

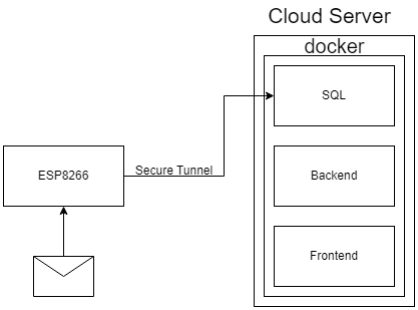
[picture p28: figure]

Figure 3.4: Cloud Server Architecture

### 3.5.3 Comparison

Table 3.1: Comparison of Physical and Cloud Servers

Criteria | Physical Server | Cloud Server
Control | Full hardware and software control | Managed environment with limited hardware access
Access to Physical Ports | Direct access allows easy integra-tion with microcontrollers | No direct hardware access; only re-mote API communication
Scalability | Suited for single-location setups | Can handle multiple devices across regions
Maintenance | Manual updates and monitoring | Automated by cloud provider (backups, updates, monitoring)
Reliability | Dependent on local uptime and power stability | High availability via redundant in-frastructure
Remote Access | Requires extra configuration (e.g., port forwarding) | Accessible globally with public DNS/IP
Operational Costs | One-time hardware purchase | Pay-as-you-go or subscription model
Internet Dependency | Can function offline temporarily | Must be online to send/receive data
Setup Complexity | Simpler to understand and debug locally | Requires familiarity with cloud tools and services
Security | Controlled locally; less exposed but depends on user | Requires cloud security hardening (firewalls, IAM, etc.)

### 3.6 False Alarm Detection

To rule out if a seismic event is an earthquake or not, we would follow two main steps, first we check the peak frequency and see if it fits in the thresholds, if it doesn’t then we automatically rule it out as not an earthquake, however if it does fit that threshold then we send the acceleration data to an AI model which can determine if it’s an earthquake or not.

### 3.6.1 Peak Frequency Check

We begin by analyzing the peak frequency of accelerations to identify potential earthquakes. If the peak frequency falls within the earthquake detection range of 1-20 Hz, we proceed with classification using various machine learning models. If the frequency does not fall within this range, the data is classified as a false alarm.

### 3.6.2 Machine Learning Models

We’ve tried multiple machine learning models to see which one would perform best, and each model will be tested with the first 200, 500 and 1000 acceleration data to see which would be the best, the ideal model should provide high accuracy at the least number of acceleration data since that means it can determine if it’s a false alarm faster, since this system is mainly a warning system, its extremely important for the fastest warning possible but at the same time at as good of an accuracy as possible. For all the models we would do whats known as a 70/30 split where 70% of the data would be used for training and 30% for testing, we’ll be using 100 earthquake signals and 100 noise signals (not earthquakes).

### 3.6.3 Naive Bayes Model

Naive Bayes is a probabilistic machine learning model based on Bayes’ theorem, which assumes that features are independent of each other (hence "naive"). It works by calculating the posterior probability of each class (in this case, earthquake or not), given the features of the data. It then classifies the data into the class with the highest posterior probability [35].
Below are the results of using the Naive Bayes model for false alarm detection across datasets with 200, 500, and 1000 accelerations:

Table 3.2: Naive Bayes Model Results for False Alarm Detection

Accelerations | Accuracy (%) | Precision (%) | Recall (%) | F1 Score (%) | False Positive Rate (%) | True Negative Rate (%) | False Negative Rate (%)
200 | 58.93 | 100.0 | 23.33 | 37.84 | 0.0 | 100.0 | 76.67
500 | 63.64 | 100.0 | 28.57 | 44.44 | 0.0 | 100.0 | 71.43
1000 | 65.45 | 100.0 | 29.63 | 45.71 | 0.0 | 100.0 | 70.37

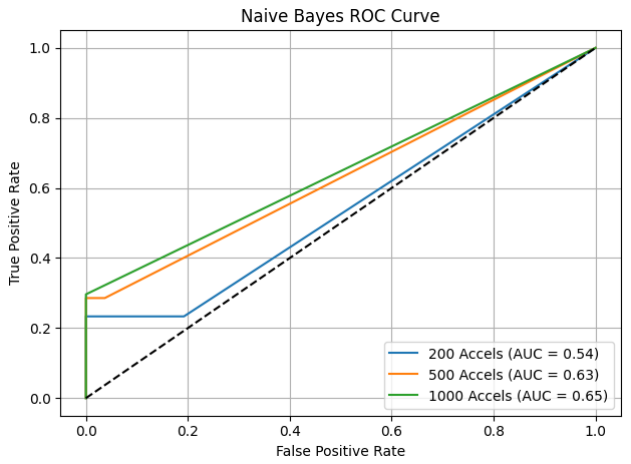
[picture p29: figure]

Figure 3.5: ROC Curve of Gradient Boosting Model

Comments on Naive Bayes Results:

- 200 Accelerations:

– Accuracy: 58.93% — Slightly better than random guessing, but too weak for deployment.

– Precision: 100% — Every predicted earthquake was correct.

– Recall: 23.33% — The model detected less than a quarter of actual earthquake events.

– F1 Score: 37.84% — Reflects poor recall despite perfect precision.

– False Negative Rate: 76.67% — A very high proportion of real earthquakes went undetected.

– ROC AUC: 54.29% — Barely above chance level, suggesting weak discriminative power.

– Comment: The model is extremely conservative, avoiding false alarms entirely but at the cost of missing most real earthquakes. Such behavior makes it ineffective for any early warning system.

- 500 Accelerations:

– Accuracy: 63.64% — Slight improvement due to increased input data.

– Precision: 100% — All earthquake predictions were correct.

– Recall: 28.57% — A small increase, but still poor.

– F1 Score: 44.44% — Slight improvement, yet still unsatisfactory.

– False Negative Rate: 71.43% — Most earthquakes still go undetected.

– ROC AUC: 62.96% — Better than at 200 accelerations but still mediocre.

– Comment: While it improves with more data, the model remains far too cautious. The extremely high threshold for earthquake classification limits its usefulness in real-time scenarios.

- 1000 Accelerations:

– Accuracy: 65.45% — Best of the three configurations, but still far from ideal.

– Precision: 100% — Maintains flawless precision on earthquake predictions.

– Recall: 29.63% — Only marginally better than at 500 accelerations.

– F1 Score: 45.71% — Moderate improvement, but still reflects the underlying imbalance.

– False Negative Rate: 70.37% — Nearly three out of four earthquakes are missed.

– ROC AUC: 64.81% — The highest AUC among the three, but still insufficient.

– Comment: Despite minor improvements, the model’s conservative bias persists. It fails to provide the kind of sensitivity needed in early warning systems, making it inadequate for real-world deployment.

### 3.6.4 Gradient Boosting Model

Gradient Boosting is an ensemble learning technique where multiple weak learners (usually decision trees) are trained sequentially. Each tree attempts to correct the errors of the previous tree by focusing on the data points that were misclassified. Over time, the model improves its performance through this iterative correction process [36]. Below are the results for the Gradient Boosting model:

Table 3.3: Gradient Boosting Model Results for False Alarm Detection

Accelerations | Accuracy (%) | Precision (%) | Recall (%) | F1 Score (%) | False Positive Rate (%) | True Negative Rate (%) | False Negative Rate (%)
200 | 85.42 | 81.48 | 91.67 | 86.27 | 20.83 | 79.17 | 8.33
500 | 87.50 | 84.00 | 91.30 | 87.50 | 16.00 | 84.00 | 8.70
1000 | 91.49 | 91.30 | 91.30 | 91.30 | 8.33 | 91.67 | 8.70

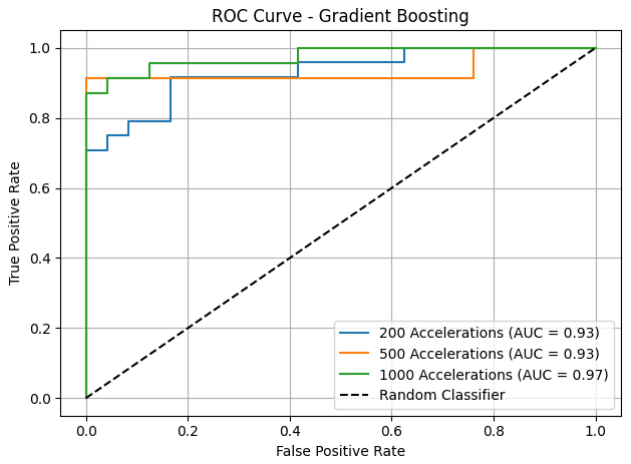
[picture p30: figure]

Figure 3.6: ROC Curve of Gradient Boosting Model

Comments on the Gradient Boosting Results:

- 200 Accelerations:

– Accuracy: 85.42% — Indicates good overall classification performance.

– Precision: 81.48% — Most predicted earthquake events were correct, though some false positives remain.

– Recall: 91.67% — The model successfully captured nearly all real earthquake events.

– F1 Score: 86.27% — Demonstrates strong balance between false positives and missed detections.

– False Positive Rate: 20.83% — False alarms are present but may be tolerable in early warning contexts.

– ROC AUC: 93.06% — The model performs very well across all threshold levels, showing strong class separability even at low input sizes.

– Comment: At just 200 acceleration points, the model performs well with excellent recall and a high AUC. However, its higher false positive rate may still require additional filtering to avoid unnecessary alarms.

- 500 Accelerations:

– Accuracy: 87.50% — Slight improvement, indicating more balanced predictions.

– Precision: 84.00% — Slightly better than at 200, meaning fewer false positives.

– Recall: 91.30% — Still excellent, maintaining strong detection of real earthquakes.

– F1 Score: 87.50% — Reflects a high-quality classification.

– False Positive Rate: 16.00% — Lower false alarms than before, making this configuration more favorable.

– ROC AUC: 93.39% — Slightly improved over the previous case, affirming the model’s reliability across decision thresholds.

– Comment: The model performs better as input length increases, reducing false positives while preserving detection quality. The high AUC reinforces its reliability for critical systems.

- 1000 Accelerations:

– Accuracy: 91.49% — Highest accuracy among the three configurations.

– Precision & Recall: 91.30% — A perfect balance, with very few missed events and low false positives.

– F1 Score: 91.30% — Indicates overall robustness in prediction.

– False Positive Rate: 8.33% — Very low, signaling minimal false alarms.

– ROC AUC: 97.46% — Excellent ROC performance; the model offers nearly perfect discrimination between earthquake and non-earthquake cases.

– Comment: This configuration yields the most consistent and reliable performance. The high AUC, combined with balanced precision and recall, make it the most dependable setting, especially for safety-critical applications where minimizing missed detections and false alarms is paramount.

### 3.6.5 LightGBM Model

LightGBM (Light Gradient Boosting Machine) is another variant of gradient boosting that is designed to be more efficient and scalable. It builds trees in a leaf-wise manner (rather than level-wise as in traditional gradient boosting), which often results in faster training (up to 20 times faster) and better performance on large datasets. It also uses histogram-based algorithms, which can speed up the process and handle large datasets efficiently [37].
Below are the results for the LightGBM model:

Table 3.4: LightGBM Model Results for False Alarm Detection

Accelerations | Accuracy (%) | Precision (%) | Recall (%) | F1 Score (%) | False Positive Rate | True Negative Rate | False Negative Rate
200 | 81.25 | 75.86 | 91.67 | 83.02 | 29.17 | 70.83 | 8.33
500 | 93.75 | 95.45 | 91.30 | 93.33 | 4.00 | 96.00 | 8.70
1000 | 93.62 | 95.45 | 91.30 | 93.33 | 4.17 | 95.83 | 8.70

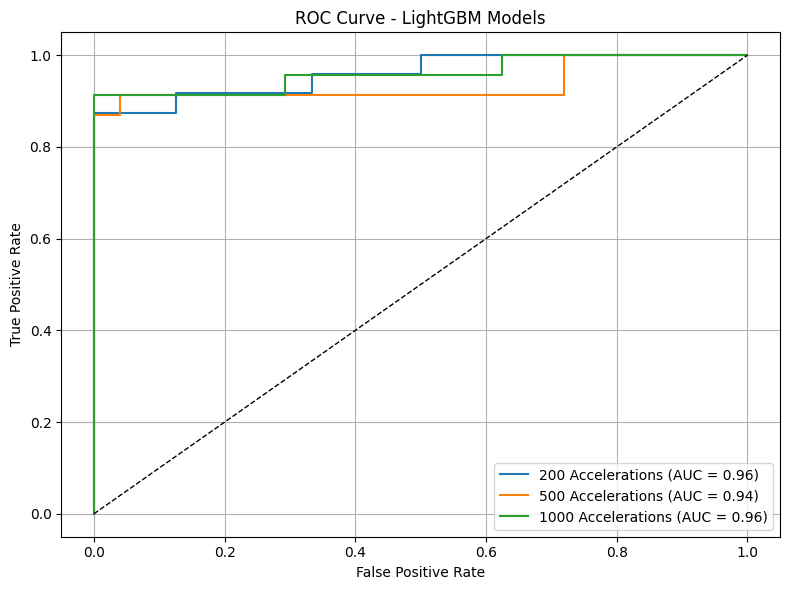
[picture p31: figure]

Figure 3.7: ROC Curve of LightGBM Model

Comment on LightGBM Results:

- 200 Accelerations:

– Accuracy: 81.25% — Decent performance, but less consistent than expected at lower input volume.

– Precision: 75.86% — Indicates that one in four alarms was a false positive.

– Recall: 91.67% — The model still captured most of the real earthquakes.

– F1 Score: 83.02% — Reflects a modest balance between detecting real events and avoiding false alarms.

– False Positive Rate: 29.17% — Almost one-third of the non-earthquake cases were falsely flagged.

– ROC AUC: 96.01% — Despite imperfect predictions, the classifier’s ability to separate classes is excellent.

– Comment: This configuration shows promising separation power but a high false positive rate. It would require post-processing (e.g., threshold tuning) before deployment.

- 500 Accelerations:

– Accuracy: 93.75% — A substantial improvement over the 200-acceleration case.

– Precision: 95.45% — Nearly all predicted earthquake events are correct.

– Recall: 91.30% — Maintains strong detection of real earthquakes.

– F1 Score: 93.33% — Indicates very strong overall classification performance.

– False Positive Rate: 4.00% — Minimal false alarms enhance reliability.

– ROC AUC: 93.57% — Confirms strong class separability and reliable scoring.

– Comment: With low false alarms and high recall, this is a balanced and deployment-ready configuration. The AUC score reinforces that the model ranks earthquake likelihood effectively.

- 1000 Accelerations:

– Accuracy: 93.62% — Almost identical to the 500-acceleration result.

– Precision: 95.45% — Excellent precision with minimal false alarms.

– Recall: 91.30% — No loss in sensitivity compared to the 500-sample case.

– F1 Score: 93.33% — Shows consistent performance even as input data increases.

– False Positive Rate: 4.17% — Maintains low false alarms.

– ROC AUC: 96.01% — Matches the 200-acceleration AUC, showing that the model maintains strong class separation even as the input grows.

– Comment: This setup ensures reliable classification with great separation power. However, compared to 500-acceleration input, it doesn’t offer significant gains, implying 500 might be the most efficient configuration.

### 3.6.6 Random Forest Model

Random Forest is an ensemble method that constructs multiple decision trees during training and outputs the mode of the classes predicted by individual trees. The model mitigates overfitting by averaging the results of many decision trees, each trained on a random subset of the data [38].
Finally, here are the results for the Random Forest model:

Table 3.5: Random Forest Model Results for False Alarm Detection

Accelerations | Accuracy (%) | Precision (%) | Recall (%) | F1 Score (%) | False Positive Rate | True Negative Rate | False Negative Rate
200 | 94.64 | 96.55 | 93.33 | 94.92 | 3.85 | 96.15 | 6.67
500 | 96.36 | 100.0 | 92.86 | 96.30 | 0.00 | 100.0 | 7.14
1000 | 96.36 | 100.0 | 92.59 | 96.15 | 0.00 | 100.0 | 7.41

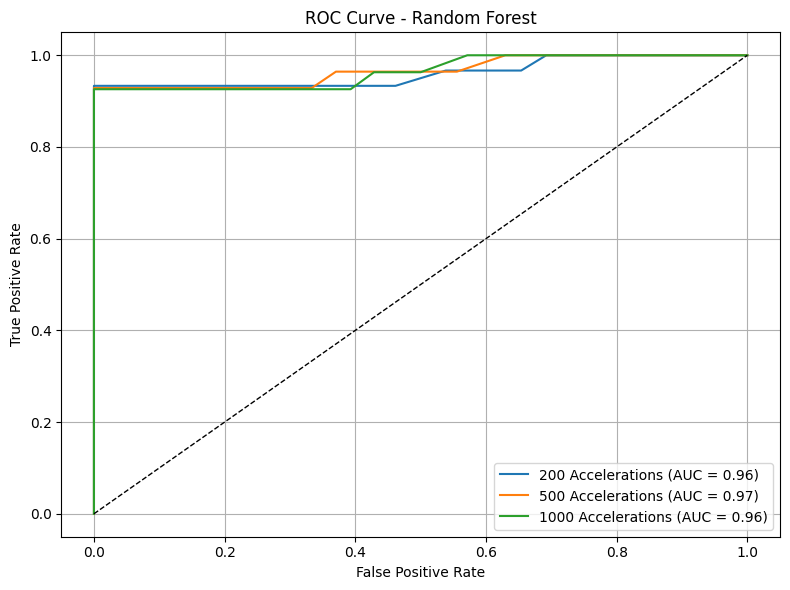
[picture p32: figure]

Figure 3.8: ROC Curve of Random Forest Model

Comments on Random Forest Results:

- 200 Accelerations:

– Accuracy: 94.64% — Strong and reliable performance from a small dataset.

– Precision: 96.55% — Nearly all detected earthquakes were correct, showing very few false positives.

– Recall: 93.33% — Most actual earthquakes were successfully identified.

– F1 Score: 94.92% — A near-perfect balance between detection and false alarms.

– False Positive Rate: 3.85% — Very few false alarms.

– ROC AUC: 96.09% — Excellent class separation with high reliability even at lower input size.

– Comment: The model is highly accurate and well-balanced even with only 200 data points, making it suitable for rapid deployment in real-time systems.

- 500 Accelerations:

– Accuracy: 96.36% — Excellent performance across the board.

– Precision: 100.0% — All detected earthquakes were actual events — zero false positives.

– Recall: 92.86% — Very few missed detections.

– F1 Score: 96.30% — Near-perfect score balancing precision and recall.

– False Positive Rate: 0.00% — No false alarms occurred.

– ROC AUC: 96.63% — Outstanding separability and highly dependable decision thresholds.

– Comment: At 500 acceleration readings, Random Forest provides its strongest and most reliable output, making it the optimal configuration for this system. The combination of speed, accuracy, and ROC AUC make this setup ideal.

- 1000 Accelerations:

– Accuracy: 96.36% — Maintains same excellent performance as at 500 readings.

– Precision: 100.0% — Perfect detection with no false earthquake alerts.

– Recall: 92.59% — Slightly lower than 500 but still excellent.

– F1 Score: 96.15% — High accuracy maintained with a stable prediction balance.

– False Positive Rate: 0.00% — Zero false alarms again.

– ROC AUC: 96.49% — Demonstrates consistent and highly effective class separation.

– Comment: The performance is nearly identical to the 500-reading configuration, but requires more data to achieve the same result. Thus, the 500-point setup remains the best balance between speed and accuracy.

### 3.6.7 Which Model Would Be Chosen?

After comparing the performance of all tested models across different acceleration sample sizes, Random Forest emerges as the most suitable model for our earthquake false alarm detection system. While each model has its own strengths and weaknesses, Random Forest provided the best trade-off between classification accuracy and the amount of input data needed.
Naive Bayes showed very poor recall, particularly at smaller input sizes, and failed to detect the majority of real earthquakes despite perfect precision. This overly conservative behavior makes it unsuitable for our use case, where missing an actual earthquake is far more dangerous than raising a false alarm.
Gradient Boosting performed admirably, with strong recall and high AUC scores even at just 200 readings. However, it showed slightly more false positives than Random Forest and did not surpass it in overall accuracy, especially when both models were tested on the same sample size.

LightGBM also performed very well at higher acceleration inputs, achieving high accuracy and precision. However, its lower performance at 200 accelerations and only marginal gains after 500 made it less efficient than Random Forest in real-time scenarios.
Random Forest, by contrast, achieved a high accuracy of 94.64% at just 200 accelerations, and rose to 96.36% at 500 readings matching its performance at 1000. This stability indicates that 500 readings are sufficient for optimal performance, but at 200 accelerations readings still maintains a good accuracy and can output a result at less than half the readings making it more efficient. It maintained excellent precision and recall, along with a low false positive rate. Furthermore, Random Forest’s architecture allows for rapid training and inference, making it ideal for a system that must quickly determine whether a seismic event is a genuine earthquake or a false alarm.
So in conclusion, Based on its ability to achieve high accuracy quickly (with as few as 200 accelerations), its balanced performance across all key metrics, and its faster computation time compared to other models, Random Forest is the chosen model for our system.

### 3.7 Summary

This chapter outlines the foundational components and methodologies employed in the IoT-based earthquake detection system. It begins with the interpretation of accelerometer data, which is recorded in gravitational units and converted into total acceleration magnitude. Through a two-stage trapezoidal integration method, acceleration is translated into displacement, enabling the estimation of earthquake strength using the Richter magnitude scale. A key feature of the system is its ability to determine the epicentral distance using P-wave and S-wave arrival times, which further refines magnitude calculation.
The chapter also explores earthquake frequency characteristics and how Fast Fourier Transform (FFT) is used to extract dominant frequency components from seismic data. Low-pass filtering is applied to remove noise and enhance detection reliability. Additionally, the chapter discusses server-side design—both physical and cloud—focusing on data logging, visualization, and system scalability. Finally, several false alarm reduction strategies are introduced, including both frequency thresholding and machine learning models, with a Random Forest model emerging as a preferred classifier based on accuracy and balance.
These techniques collectively form the scientific and computational backbone of the system, establishing the basis for real-time, accurate earthquake detection.

## Chapter 4

# Proposed System Design

### 4.1 Industry Standard

The industry standards for earthquake detection systems integrate advanced technologies to ensure accurate and timely monitoring and alerts. Below are some key aspects of modern systems and technologies:

1. Sensor Networks: Systems like Japan’s Earthquake Early Warning (EEW) [8], California’s ShakeAlert [39] and the Canadian Earthquake Early Warning [40] use real-time data from sensor networks to provide warnings seconds before destructive seismic waves arrive, they utilizes dense arrays of high-sensitivity seismometers and MEMS sensors. MEMS sensors are compact, cost-effective, and widely deployed in various settings, including smartphones and IoT devices [4]. These systems detect the p-wave of an earthquake and once its detected it send the warning right away, then it continues measuring earthquake seismic data until its over to analyze the data [40].
2. Frequency and Signal Filtering: Advanced frequency analysis methods, such as Fourier Transforms, and filtering mechanisms like band-pass, these filters are used to differentiate between seismic activity and other vibrations, it can also be used to analyze the seismic activity data more easily [41].
3. Satellite-Based Technologies: Systems such as InSAR use satellite imagery to detect ground deformation, providing valuable insights into seismic activity [42].
4. Communication Protocols: IoT-based communication protocols improve the transmission of real-time data between distributed sensors and the system. These protocols are designed to ensure low latency and high reliability [43], crucial for effective warnings.

### 4.2 Requirement Analysis

To cover our system requirements, lets divide it into four sections. Hardware requirements, software requirements, functional requirements and non-functional requirements.

### 4.2.1 Hardware Requirements

The hardware requirements consists of 5 main parts which are the sensors, microntroller, communication module, power supply, and the peripheral components.

- Sensors: Firstly, we need sensors to be able to detect an earthquake. Generally, most projects use both an accelerometer and an gyroscope to detect an earthquake, however we want to save costs while not majorly affect the results so we chose to use just an accelerometer as our sensor, however there’s three kinds of accelerometer which are 1-Axis accelerometer, 2-Axis accelerometer and 3-axis accelerometer so lets cover each one briefly.

– 1-Axis Accelerometer: Measures acceleration along a single axis, however since its only one axis its accuracy won’t be the best for our project, so we can reject this option.

– 2-Axis Accelerometers: Measures acceleration along two perpendicular axes (X and Y), while its more accurate than the 1-axis accelerometer. It still won’t have enough accuracy for our system, so we can reject this option as well.

– 3-axis Accelerometer: Measures acceleration along three perpendicular axes (X, Y, and Z). These are the most common and versatile accelerometers, used in applications like smartphones, fitness trackers, and most importantly earthquake detection devices, and it has the best accuracy therefore we have decided this is the best type of accelerometer to use for our project

- Microcontroller: For our microcontroller we want a cheap microcontroller however we want it to have a good memory, low abstraction level and to be able to receive data from the sensors and send it, so our choices were between ATmega32, Arduino and STM32 so lets go between each one of them

– ATmega32: Out of these 3 microcontrollers, this is the cheapest microcontroller and it provides a low level abstraction, however its memory size is smaller than what we would need for this project so we can eliminate this choice.

– Arduino: Its the most expensive option and it provides a high-level abstraction so we can elimnate this choice too.

– STM32: Eventhough its a little more expensive than ATMEGA32 but its still relatively cheap, it also provides a low-level abstraction, it has a good memory size and low power consumption [44] so it fits all the requirements of our project.

- Communication Modules: Our project consists of two sides, the station side and the server side so for these two sides to communicate we need a communication module that would be capable of reliably communicating almost anywhere, we have 3 have choosen options as a way for data transmission which are Bluetooth, Wi-Fi and Radio waves.

– Bluetooth: A Bluetooth module can provide reliable data transmission however bluetooth only works within very short distances of couple meters, when we need communication over a long so we can remove bluetooth as an option.

– Radio waves: To communicate with radio waves we would use LoRa which provides reliable data transmission and can transmit over long distances up to 10 km and radio waves could be used anywhere making the system very remote, however LoRa has a low data rate of 0.3-27Kbps [45] and radio waves have an issue with multipath propagation which would force us to place the station in an empty area with no obstacles or buildings otherwise it would cause delays and reflected signals arriving at different times could confuse the system [46], and another major issue with LoRa is its legallity where its illegal in some countries like Egypt [47], therefore we chose not to choose it.

– Wi-Fi: A Wi-Fi module can provide reliable and fast data transmission (2.7 Mbps [48]) and it can be used anywhere as long as there is a WiFi connection making it very remote, therefore we decided to choose it for our project

- Power Supply:-

– Li-ion Batteries: Provides the power source for the station.

– Battery Case: Simplifies battery connection and replacement.

- Peripheral Components:-

– STM32 Programmer: To upload and burn code to the STM32 microcontroller.

– Wires and Breadboard: Used for prototyping and circuit connections (Breadboard will be used in the testing phase then later it will be placed onto a PCB board).

### 4.2.2 Software Requirements

The software requirements consists of 4 main parts which are development environments, Programming Languages, Server Management and visualization and monitoring

- Development Environments:We needed a development environment with a low level of abstraction, minimal configuration, and compatibility with STM32. To identify the most suitable platform for our project, we assessed three different Integrated Development Environments (IDEs). The options we reviewed:
1. Arduino IDE: Eventhough its easy to use, arduino IDE has a high level abstraction [49] therefore we did not select this IDE. This restriction prevents us from accessing and modifying key components of the underlying code and hardware interactions, which are critical for gaining insights and optimizing the system.
2. Eclipse IDE: It is a low level abstraction however it has difficult configurations and doesn’t support STM32 without the usage of a third party software therefore we did not select this.
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

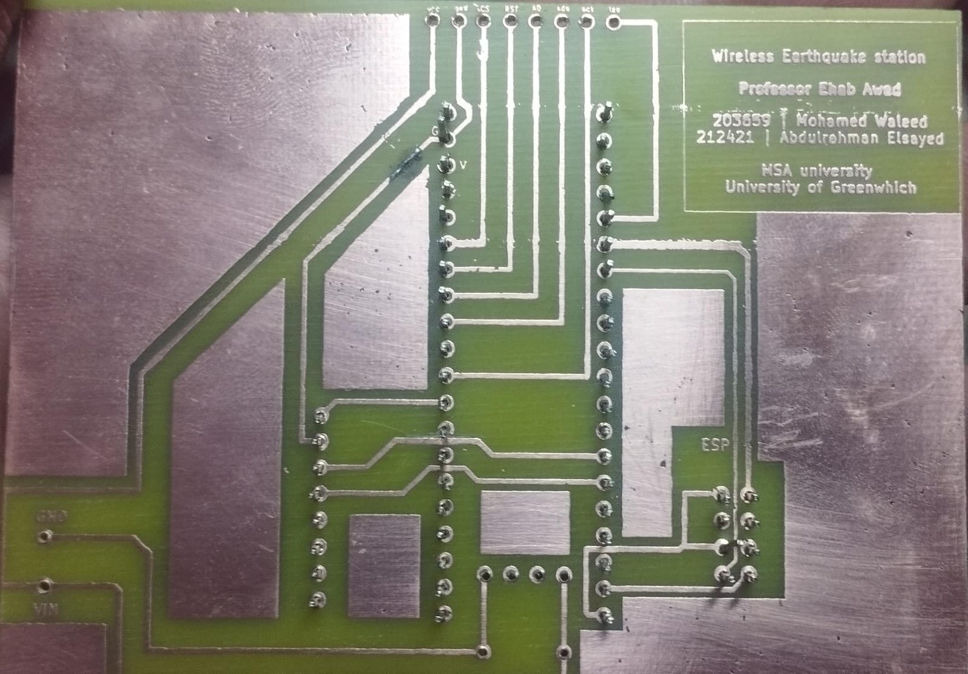
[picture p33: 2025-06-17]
images/af909980-b785-4e5a-b30e-7de9cf03099e.jpeg

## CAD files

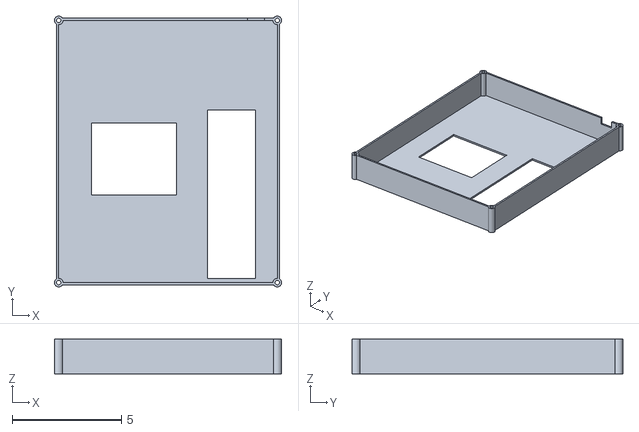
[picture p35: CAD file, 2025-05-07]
Design Autocad/cover.stl
10.4 x 12.4 x 1.60

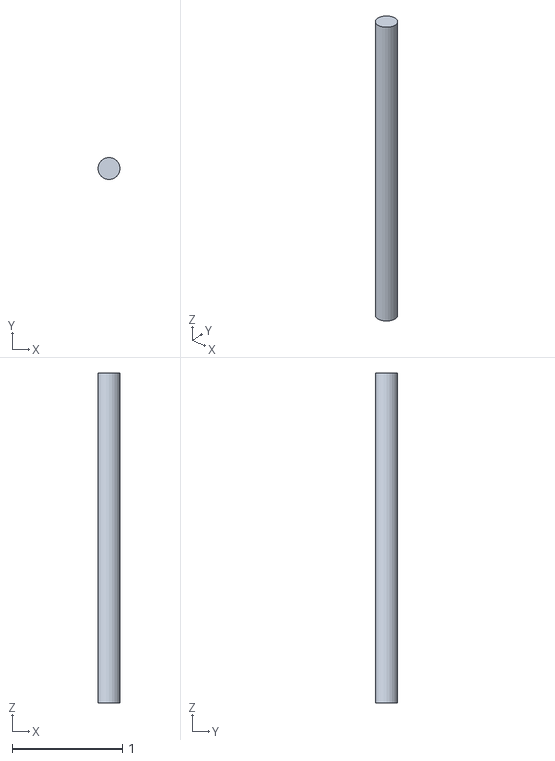
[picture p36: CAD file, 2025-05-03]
Design Autocad/pins.stl
0.2 x 0.2 x 3.00

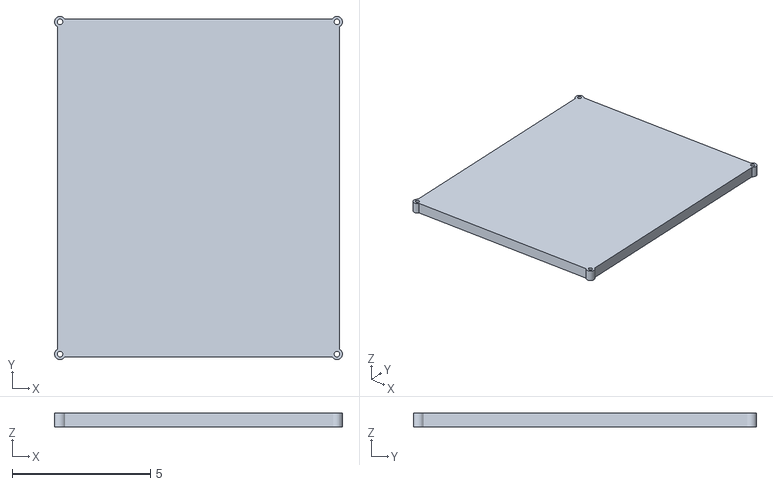
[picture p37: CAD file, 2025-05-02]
Design Autocad/base.stl
10.4 x 12.4 x 0.5

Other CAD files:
Design Autocad/base.dwg
Design Autocad/cover.dwg
Design Autocad/pins.dwg

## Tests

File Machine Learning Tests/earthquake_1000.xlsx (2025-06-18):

acc1 | acc2 | acc3 | acc4 | acc5 | acc6 | acc7 | acc8 | acc9 | acc10 | acc11 | acc12 | acc13 | acc14 | acc15 | acc16 | acc17 | acc18 | acc19 | acc20 | acc21 | acc22 | acc23 | acc24 | acc25 | acc26 | acc27 | acc28 | acc29 | acc30 | acc31 | acc32 | acc33 | acc34 | acc35 | acc36 | acc37 | acc38 | acc39 | acc40 | acc41 | acc42 | acc43 | acc44 | acc45 | acc46 | acc47 | acc48 | acc49 | acc50 | acc51 | acc52 | acc53 | acc54 | acc55 | acc56 | acc57 | acc58 | acc59 | acc60
0.05232738244 | 0.07426455105 | 0.0669466832 | 0.07132306522 | 0.0681873883 | 0.07061389492 | 0.06861722641 | 0.07029451792 | 0.06882869846 | 0.07010928282 | 0.0689506627 | 0.06998458536 | 0.06902721332 | 0.06989474492 | 0.06907788187 | 0.06982414466 | 0.06911041376 | 0.06976655518 | 0.06913417391 | 0.06971614782 | 0.06914737527 | 0.06967181311 | 0.06915587408 | 0.06963566958 | 0.06916450213 | 0.0695971929 | 0.0691566336 | 0.06956453192 | 0.06916047904 | 0.06953450642 | 0.06915459855 | 0.06949922016 | 0.06914732991 | 0.06947308152 | 0.06913730803 | 0.06944539915 | 0.06912456459 | 0.06942041514 | 0.06911191315 | 0.06937967706 | 0.06910677242 | 0.06936522836 | 0.06909702923 | 0.06933139735 | 0.06905713094 | 0.06930901745 |
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

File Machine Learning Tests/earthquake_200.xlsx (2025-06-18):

acc1 | acc2 | acc3 | acc4 | acc5 | acc6 | acc7 | acc8 | acc9 | acc10 | acc11 | acc12 | acc13 | acc14 | acc15 | acc16 | acc17 | acc18 | acc19 | acc20 | acc21 | acc22 | acc23 | acc24 | acc25 | acc26 | acc27 | acc28 | acc29 | acc30 | acc31 | acc32 | acc33 | acc34 | acc35 | acc36 | acc37 | acc38 | acc39 | acc40 | acc41 | acc42 | acc43 | acc44 | acc45 | acc46 | acc47 | acc48 | acc49 | acc50 | acc51 | acc52 | acc53 | acc54 | acc55 | acc56 | acc57 | acc58 | acc59 | acc60
0.05232738244 | 0.07426455105 | 0.0669466832 | 0.07132306522 | 0.0681873883 | 0.07061389492 | 0.06861722641 | 0.07029451792 | 0.06882869846 | 0.07010928282 | 0.0689506627 | 0.06998458536 | 0.06902721332 | 0.06989474492 | 0.06907788187 | 0.06982414466 | 0.06911041376 | 0.06976655518 | 0.06913417391 | 0.06971614782 | 0.06914737527 | 0.06967181311 | 0.06915587408 | 0.06963566958 | 0.06916450213 | 0.0695971929 | 0.0691566336 | 0.06956453192 | 0.06916047904 | 0.06953450642 | 0.06915459855 | 0.06949922016 | 0.06914732991 | 0.06947308152 | 0.06913730803 | 0.06944539915 | 0.06912456459 | 0.06942041514 | 0.06911191315 | 0.06937967706 | 0.06910677242 | 0.06936522836 | 0.06909702923 | 0.06933139735 | 0.06905713094 | 0.06930901745 |
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

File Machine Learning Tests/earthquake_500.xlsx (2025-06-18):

acc1 | acc2 | acc3 | acc4 | acc5 | acc6 | acc7 | acc8 | acc9 | acc10 | acc11 | acc12 | acc13 | acc14 | acc15 | acc16 | acc17 | acc18 | acc19 | acc20 | acc21 | acc22 | acc23 | acc24 | acc25 | acc26 | acc27 | acc28 | acc29 | acc30 | acc31 | acc32 | acc33 | acc34 | acc35 | acc36 | acc37 | acc38 | acc39 | acc40 | acc41 | acc42 | acc43 | acc44 | acc45 | acc46 | acc47 | acc48 | acc49 | acc50 | acc51 | acc52 | acc53 | acc54 | acc55 | acc56 | acc57 | acc58 | acc59 | acc60
0.05232738244 | 0.07426455105 | 0.0669466832 | 0.07132306522 | 0.0681873883 | 0.07061389492 | 0.06861722641 | 0.07029451792 | 0.06882869846 | 0.07010928282 | 0.0689506627 | 0.06998458536 | 0.06902721332 | 0.06989474492 | 0.06907788187 | 0.06982414466 | 0.06911041376 | 0.06976655518 | 0.06913417391 | 0.06971614782 | 0.06914737527 | 0.06967181311 | 0.06915587408 | 0.06963566958 | 0.06916450213 | 0.0695971929 | 0.0691566336 | 0.06956453192 | 0.06916047904 | 0.06953450642 | 0.06915459855 | 0.06949922016 | 0.06914732991 | 0.06947308152 | 0.06913730803 | 0.06944539915 | 0.06912456459 | 0.06942041514 | 0.06911191315 | 0.06937967706 | 0.06910677242 | 0.06936522836 | 0.06909702923 | 0.06933139735 | 0.06905713094 | 0.06930901745 |
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

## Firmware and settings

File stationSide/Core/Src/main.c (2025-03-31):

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
/* Includes ------------------------------------------------------------------*/
#include "main.h"

/* USER CODE BEGIN Includes */
#include "ESP01.h"
#include "MPU6050.h"
#include "st7735.h"
#include "fonts.h"
/* USER CODE END Includes */

I2C_HandleTypeDef hi2c1;

IWDG_HandleTypeDef hiwdg;

SPI_HandleTypeDef hspi1;

UART_HandleTypeDef huart1;

void SystemClock_Config(void);
static void MX_GPIO_Init(void);
static void MX_USART1_UART_Init(void);
static void MX_I2C1_Init(void);
static void MX_IWDG_Init(void);
static void MX_SPI1_Init(void);
/* USER CODE BEGIN PFP */
volatile uint8_t uart_rx_data = 0;
void HAL_UART_RxCpltCallback(UART_HandleTypeDef *huart)
{
    if (huart->Instance == USART1)  // Check if the interrupt is from USART1
    {
        if (uart_rx_data == '0')  // If received data is '0', restart the system
        {
            NVIC_SystemReset();
        }
        HAL_UART_Receive_IT(&huart1, &uart_rx_data, 1);  // Re-enable UART receive interrupt
    }
}
/* USER CODE END PFP */

/**
  * @brief  The application entry point.
  * @retval int
  */
int main(void)
{

  /* MCU Configuration--------------------------------------------------------*/

  /* Reset of all peripherals, Initializes the Flash interface and the Systick. */
  HAL_Init();

  /* Configure the system clock */
  SystemClock_Config();

  /* Initialize all configured peripherals */
  MX_GPIO_Init();
  MX_USART1_UART_Init();
  MX_I2C1_Init();
  MX_IWDG_Init();
  MX_SPI1_Init();
  /* USER CODE BEGIN 2 */
  HAL_GPIO_WritePin(GPIOA, GPIO_PIN_4,1);//enable accelrometer


  ST7735_Init();

  HAL_IWDG_Refresh(&hiwdg);

  HAL_GPIO_WritePin(GPIOA, GPIO_PIN_8,1);
  ESP_Init();
  MPU6050_Init(&hi2c1);

  ST7735_WriteString(11, STATION_Y,"STATION IS WORKING..", Font_5x8, ST7735_GREEN, ST7735_BLACK);
  HAL_IWDG_Refresh(&hiwdg);
  float accelMagnitude=0;


  /* USER CODE END 2 */

  /* Infinite loop */
  /* USER CODE BEGIN WHILE */
   //HAL_UART_Receive_IT(&huart1, &uart_rx_data, 1);
  int x=0;
  ST7735_FillRectangleFast(0, ACCEL_Y, 128, 50, ST7735_BLACK);
  ST7735_WriteString(20, ACCEL_Y,"ACC IS WORKING..", Font_5x8, ST7735_GREEN, ST7735_BLACK);
  while (1)
  {

	  accelMagnitude=MPU6050_Read_Accel(&hi2c1);
	  if ( accelMagnitude==0 ){ //
		  HAL_IWDG_Refresh(&hiwdg);

		  x+=1;
		  if (x==500){
			 HAL_GPIO_WritePin(GPIOA, GPIO_PIN_8, 0);

		  }

		  continue;
	  }
	  else if ( accelMagnitude==-1 || isnanf(accelMagnitude) ){
		  // HAL_IWDG_Refresh(&hiwdg);
		  ST7735_FillRectangleFast(0, ACCEL_Y, 128, 50, ST7735_BLACK);
		  ST7735_WriteString(20, ACCEL_Y,"ACC ERROR!!", Font_5x8, ST7735_WHITE, ST7735_BLACK);
		  ST7735_WriteString(20, ACCEL_Y+10,"RESETTING..", Font_5x8, ST7735_WHITE, ST7735_BLACK);
		  HAL_Delay(1000);
		  NVIC_SystemReset();

	  }
	  //HAL_Delay(1);
	  ESP_Send_Data( accelMagnitude, 1);
	  HAL_IWDG_Refresh(&hiwdg);
	  HAL_GPIO_WritePin(GPIOA, GPIO_PIN_8,1);

	  x=0;




    /* USER CODE END WHILE */

    /* USER CODE BEGIN 3 */
  }
  /* USER CODE END 3 */
}

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


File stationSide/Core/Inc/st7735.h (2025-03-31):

/* vim: set ai et ts=4 sw=4: */
#ifndef __ST7735_H__
#define __ST7735_H__

#include "fonts.h"
#include <stdbool.h>



#define STATION_Y	15
#define ESP_Y		55
#define ACCEL_Y		120

#define ST7735_MADCTL_MY  0x80
#define ST7735_MADCTL_MX  0x40
#define ST7735_MADCTL_MV  0x20
#define ST7735_MADCTL_ML  0x10
#define ST7735_MADCTL_RGB 0x00
#define ST7735_MADCTL_BGR 0x08
#define ST7735_MADCTL_MH  0x04

/*** Redefine if necessary ***/
#define ST7735_SPI_PORT hspi1
extern SPI_HandleTypeDef ST7735_SPI_PORT;

#define ST7735_RES_Pin       GPIO_PIN_1
#define ST7735_RES_GPIO_Port GPIOB
#define ST7735_CS_Pin        GPIO_PIN_10
#define ST7735_CS_GPIO_Port  GPIOB
#define ST7735_DC_Pin        GPIO_PIN_0
#define ST7735_DC_GPIO_Port  GPIOB

// AliExpress/eBay 1.8" display, default orientation
/*
#define ST7735_IS_160X128 1
#define ST7735_WIDTH  128
#define ST7735_HEIGHT 160
#define ST7735_XSTART 0
#define ST7735_YSTART 0
#define ST7735_ROTATION (ST7735_MADCTL_MX | ST7735_MADCTL_MY)
*/

// AliExpress/eBay 1.8" display, rotate right
/*
#define ST7735_IS_160X128 1
#define ST7735_WIDTH  160
#define ST7735_HEIGHT 128
#define ST7735_XSTART 0
#define ST7735_YSTART 0
#define ST7735_ROTATION (ST7735_MADCTL_MY | ST7735_MADCTL_MV)
*/

// AliExpress/eBay 1.8" display, rotate left
/*
#define ST7735_IS_160X128 1
#define ST7735_WIDTH  160
#define ST7735_HEIGHT 128
#define ST7735_XSTART 0
#define ST7735_YSTART 0
#define ST7735_ROTATION (ST7735_MADCTL_MX | ST7735_MADCTL_MV)
*/

// AliExpress/eBay 1.8" display, upside down
/*
#define ST7735_IS_160X128 1
#define ST7735_WIDTH  128
#define ST7735_HEIGHT 160
#define ST7735_XSTART 0
#define ST7735_YSTART 0
#define ST7735_ROTATION (0)
*/

// WaveShare ST7735S-based 1.8" display, default orientation
/*
#define ST7735_IS_160X128 1
#define ST7735_WIDTH  128
#define ST7735_HEIGHT 160
#define ST7735_XSTART 2
#define ST7735_YSTART 1
#define ST7735_ROTATION (ST7735_MADCTL_MX | ST7735_MADCTL_MY | ST7735_MADCTL_RGB)
*/

// WaveShare ST7735S-based 1.8" display, rotate right
/*
#define ST7735_IS_160X128 1
#define ST7735_WIDTH  160
#define ST7735_HEIGHT 128
#define ST7735_XSTART 1
#define ST7735_YSTART 2
#define ST7735_ROTATION (ST7735_MADCTL_MY | ST7735_MADCTL_MV | ST7735_MADCTL_RGB)
*/

// WaveShare ST7735S-based 1.8" display, rotate left
/*
#define ST7735_IS_160X128 1
#define ST7735_WIDTH  160
#define ST7735_HEIGHT 128
#define ST7735_XSTART 1
#define ST7735_YSTART 2
#define ST7735_ROTATION (ST7735_MADCTL_MX | ST7735_MADCTL_MV | ST7735_MADCTL_RGB)
*/

// WaveShare ST7735S-based 1.8" display, upside down
/*
#define ST7735_IS_160X128 1
#define ST7735_WIDTH  128
#define ST7735_HEIGHT 160
#define ST7735_XSTART 2
#define ST7735_YSTART 1
#define ST7735_ROTATION (ST7735_MADCTL_RGB)
*/



//works fine ---->
 //1.44" display, default orientation

#define ST7735_IS_160X128 1
#define ST7735_WIDTH  128
#define ST7735_HEIGHT 160
#define ST7735_XSTART 0
#define ST7735_YSTART 0
#define ST7735_ROTATION (ST7735_MADCTL_MX | ST7735_MADCTL_MY )

// 1.44" display, rotate right
/*
#define ST7735_IS_128X128 1
#define ST7735_WIDTH  160
#define ST7735_HEIGHT 128
#define ST7735_XSTART 0
#define ST7735_YSTART 0
#define ST7735_ROTATION (ST7735_MADCTL_MY | ST7735_MADCTL_MV | ST7735_MADCTL_BGR)
*/

// 1.44" display, rotate left
/*
#define ST7735_IS_128X128 1
#define ST7735_WIDTH  128
#define ST7735_HEIGHT 128
#define ST7735_XSTART 1
#define ST7735_YSTART 2
#define ST7735_ROTATION (ST7735_MADCTL_MX | ST7735_MADCTL_MV | ST7735_MADCTL_BGR)
*/

// 1.44" display, upside down
/*
#define ST7735_IS_128X128 1
#define ST7735_WIDTH  128
#define ST7735_HEIGHT 128
#define ST7735_XSTART 2
#define ST7735_YSTART 1
#define ST7735_ROTATION (ST7735_MADCTL_BGR)
*/

// mini 160x80 display (it's unlikely you want the default orientation)
/*
#define ST7735_IS_160X80 1
#define ST7735_XSTART 26
#define ST7735_YSTART 1
#define ST7735_WIDTH  80
#define ST7735_HEIGHT 160
#define ST7735_ROTATION (ST7735_MADCTL_MX | ST7735_MADCTL_MY | ST7735_MADCTL_BGR)
*/

// mini 160x80, rotate left
/*
#define ST7735_IS_160X80 1
#define ST7735_XSTART 1
#define ST7735_YSTART 26
#define ST7735_WIDTH  160
#define ST7735_HEIGHT 80
#define ST7735_ROTATION (ST7735_MADCTL_MX | ST7735_MADCTL_MV | ST7735_MADCTL_BGR)
*/

// mini 160x80, rotate right
/*
#define ST7735_IS_160X80 1
#define ST7735_XSTART 1
#define ST7735_YSTART 26
#define ST7735_WIDTH  160
#define ST7735_HEIGHT 80
#define ST7735_ROTATION (ST7735_MADCTL_MY | ST7735_MADCTL_MV | ST7735_MADCTL_BGR)
*/

/****************************/

#define ST7735_NOP     0x00
#define ST7735_SWRESET 0x01
#define ST7735_RDDID   0x04
#define ST7735_RDDST   0x09

#define ST7735_SLPIN   0x10
#define ST7735_SLPOUT  0x11
#define ST7735_PTLON   0x12
#define ST7735_NORON   0x13

#define ST7735_INVOFF  0x20
#define ST7735_INVON   0x21
#define ST7735_GAMSET  0x26
#define ST7735_DISPOFF 0x28
#define ST7735_DISPON  0x29
#define ST7735_CASET   0x2A
#define ST7735_RASET   0x2B
#define ST7735_RAMWR   0x2C
#define ST7735_RAMRD   0x2E

#define ST7735_PTLAR   0x30
#define ST7735_COLMOD  0x3A
#define ST7735_MADCTL  0x36

#define ST7735_FRMCTR1 0xB1
#define ST7735_FRMCTR2 0xB2
#define ST7735_FRMCTR3 0xB3
#define ST7735_INVCTR  0xB4
#define ST7735_DISSET5 0xB6

#define ST7735_PWCTR1  0xC0
#define ST7735_PWCTR2  0xC1
#define ST7735_PWCTR3  0xC2
#define ST7735_PWCTR4  0xC3
#define ST7735_PWCTR5  0xC4
#define ST7735_VMCTR1  0xC5

#define ST7735_RDID1   0xDA
#define ST7735_RDID2   0xDB
#define ST7735_RDID3   0xDC
#define ST7735_RDID4   0xDD

#define ST7735_PWCTR6  0xFC

#define ST7735_GMCTRP1 0xE0
#define ST7735_GMCTRN1 0xE1

// Color definitions
#define	ST7735_BLACK   0x0000
#define	ST7735_BLUE    0x001F
#define	ST7735_RED     0xF800
#define	ST7735_GREEN   0x07E0
#define ST7735_CYAN    0x07FF
#define ST7735_MAGENTA 0xF81F
#define ST7735_YELLOW  0xFFE0
#define ST7735_WHITE   0xFFFF
#define ST7735_COLOR565(r, g, b) (((r & 0xF8) << 8) | ((g & 0xFC) << 3) | ((b & 0xF8) >> 3))

typedef enum {
	GAMMA_10 = 0x01,
	GAMMA_25 = 0x02,
	GAMMA_22 = 0x04,
	GAMMA_18 = 0x08
} GammaDef;

#ifdef __cplusplus
extern "C" {
#endif

// call before initializing any SPI devices
void ST7735_Unselect();

void ST7735_Init(void);
void ST7735_DrawPixel(uint16_t x, uint16_t y, uint16_t color);
void ST7735_WriteString(uint16_t x, uint16_t y, const char* str, FontDef font, uint16_t color, uint16_t bgcolor);
void ST7735_FillRectangle(uint16_t x, uint16_t y, uint16_t w, uint16_t h, uint16_t color);
void ST7735_FillRectangleFast(uint16_t x, uint16_t y, uint16_t w, uint16_t h, uint16_t color);
void ST7735_FillScreen(uint16_t color);
void ST7735_FillScreenFast(uint16_t color);
void ST7735_InvertColors(bool invert);
void ST7735_SetGamma(GammaDef gamma);

#ifdef __cplusplus
}
#endif

#endif // __ST7735_H__

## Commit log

2025-03-22 updated with sockets
2025-05-02 added stl model for 3d printing
    [base.stl, cover.stl]
2025-05-03 3d design
    [cover.dwg, cover.stl, pins.dwg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]
2025-06-18 Rename earthquake_1000 (9).xlsx to earthquake_1000.xlsx
    [earthquake_1000.xlsx]
2025-06-18 Rename earthquake_200 (6).xlsx to earthquake_200.xlsx
    [earthquake_200.xlsx]
2025-06-18 Rename earthquake_500 (6).xlsx to earthquake_500.xlsx
    [earthquake_500.xlsx]

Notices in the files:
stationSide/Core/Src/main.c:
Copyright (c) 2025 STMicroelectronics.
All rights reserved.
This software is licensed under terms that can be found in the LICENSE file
